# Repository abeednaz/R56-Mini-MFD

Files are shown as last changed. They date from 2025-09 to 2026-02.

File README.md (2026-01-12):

<h1>R56 MINI Cooper Multi-Function Display</h1>

---

<h2>Project Background</h2>
The second generation of BMW MINI Cooper S is a great car, but it is missing important metrology from the factory. It has a coolant temperature sensor, but there is no gauge to view the temperature. Technically a driver can view the temperature by entering a <a href="https://youtu.be/KhFTyjIRaBU?si=EUw38T1VuMLcuM9A">secret menu</a>, but this is not practical except for debugging purposes as it requires a long series of inputs to display. The car otherwise uses the coolant temperature sensor only to flash a warning light when the engine has already overheated. 

Knowledge of engine temperature is important to me for two reasons:

- Situational awareness to know when engine is up to temperature in order to use full throttle and rev range
- Situational awareness in case of cooling system failures, such as leaking plastic thermostat housing

Aftermarket solutions such as the ScanGauge II and CravenSpeed Gauge Kit exist; however I felt that the ScanGauge did not suit the interior design style of the MINI, and the CravenSpeed kit cost cost more than I was willing to spend on an accessory. This project aimed to add an engine temperature display to the MINI that fits the MINI's interior design language and to take advantage of other sensors that the vehicle has to offer.

<h2>Project Demonstrations</h2>

<h3>Scrolling through the different available sensors</h3>

https://github.com/user-attachments/assets/e3969205-8839-4358-a2c1-934d2600cd6b

<h3>Getting engine up to operating temperature</h3>

https://github.com/user-attachments/assets/219b7ffb-3163-47f8-8801-7a190b6d4f65

<h3>Boost pressure demonstration</h3>

https://github.com/user-attachments/assets/48d6ecf0-7964-4478-b5fc-5cb366bfa986

<h2>Project Block Diagram</h2>

R56_MFD_block_diagram

This project consists of the following components:
- COTS ESP32-based microcontroller with AMOLED screen
- COTS ELM327 OBD-II diagnostic code scanner
- Custom PCB to supply ELM327 and ESP32 with 5V and 12V only when vehicle ignition is switched on
- Custom PCB to provide microcontroller with button, ambient light sensor, and 5V from the power supply PCB

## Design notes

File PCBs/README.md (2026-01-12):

# PCB Overview

## OBD-II Connector Board
The connector board connects to the J1962 connector under the vehicle's steering column. Pinout of the vehicle's connector:


The connector board reroutes the battery power (pin 16) through a MOSFET switch triggered by the ignition signal (pin 1). The 12V switched power line is distributed to an ELM327 OBD-II code scanner, a 12V DC power connector, and a 12V--5V buck converter to power the gauge electronics. This allows the code scanner and gauge to only be switched on while the vehicle is in accesory mode or the engine is running, reducing the parasitic battery drain while the vehicle is off to ~145 nW.



### Connector board v2.7 rework:
Two components (SW1 and Q2) were captured incorrectly in the schematic and PCB. The rework instructions are as follows:
1. Remove SW1 and solder wire between P1 and P2
2. Cut trace at X1
3. Cut trace at X2
4. Solder wire between P3 and P4
5. Solder wire between P5 and P6

 PCB Front                 | PCB Back
:-------------------------:|:-------------------------:
conn_board_2-7_rework_front  |  conn_board_2-7_rework_back

### Assembly photos
 Soldered assembly front   | Soldered assembly back    | With connector
:-------------------------:|:-------------------------:|:--------------:|
conn_board_2-7_pic1 |  conn_board_2-7_pic2 | conn_board_2-7_pic3

## Screen Accessory Board
The screen used for this project is an off-the-shelf solution from [Waveshare](https://www.waveshare.com/wiki/ESP32-S3-Touch-AMOLED-1.75#Hardware_Description). It is a fully-contained solution with an ESP32-S3 microprocesor and a high-resolution AMOLED screen in addition to a PMIC and IMU. To adapt it for the gauge, I needed to add a button to allow a user to switch between gauges, and I needed a sensor to check the ambient light level to dim the display at night. I also needed a way to switch the gauge on and off, so I moved the switch from the OBD-II distribution board to the screen accessory board.



 PCB Front                 | PCB Back
:-------------------------:|:-------------------------:
 | 

### Assembly photos
 Soldered assembly front   | Soldered assembly back    
:-------------------------:|:-------------------------:
screen_board_1-0_assembly2 |  screen_board_1-0_assembly1

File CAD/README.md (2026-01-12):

<h1>Mechanical Design</h1>

---

This project required two mechanical assemblies: one to house the OBD-II distribution PCB, and one to attach the gauge screen to the tachometer.

<table>
  <tr>
    <th scope="row" colspan="3"><h2>OBD-II Distribution Board Assembly</h2></th>
  </tr>
  <tr>
    <td>J1962 cable assembly</td>
    <td>Board assembly</td>
    <td>Completed board enclosure</td>
  </tr>
  <tr>
    <td scope="row" colspan="3">This assembly packages the OBD-II distribution PCB along with a J1962 connector to connect the ELM327 wireless code scanner. The J1962 connector is linked to the PCB with a cable assembly with the opposite end being a Molex iGrid 16-pin connector.</td>
  </tr>
</table>

https://github.com/user-attachments/assets/be2643b0-f73f-4a08-8e7a-71b6ab15d59e

<table>
  <tr>
    <th scope="row" colspan="3"><h2>Screen Assembly</h2></th>
  </tr>
  <tr>
    <td>Gauge pod and arm assembly</td>
    <td>Gauge assembled on vehicle</td>
  </tr>
  <tr>
    <td scope="row" colspan="3">This assembly packages the ESP32 AMOLED module with its accessory PCB in a gauge pod which is mounted to the tachometer with an arm. The gauge pod conceals the button underneath the bezel for the user to scroll between different sensors. The screen bezel facing the driver is hinged from the top on two dowel pins, allowing it to flex and press the button similarly to some laptop trackpad buttons. The back bezel contains cutouts for the power switch, ambient light sensor, ESP32 module SD card, and ESP32 module USB-C connector. <br>
      The arm is adapted from a free phone holder from <a href="https://www.printables.com/model/1270372-phone-holder-for-mini-r56r57">Printables</a>. The original tachometer screws are too short when the mount is in place, so two 4mm-wide thread-forming screws were used (I cut mine to ~32mm long).</td>
  </tr>
</table>

https://github.com/user-attachments/assets/c4f2a7ac-ca11-42a1-97a8-a96c77e72be4

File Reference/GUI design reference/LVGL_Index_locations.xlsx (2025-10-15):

 | x |  | y
8 | 55 | -23 | 274
9 | 32 | 23 | 186
10 | 55 | 65 | 98
11 | 120 | 88 | 34
12 | 208 |  | 10
1 | 296 | 88 | 34
2 | 361 | 65 | 98
3 | 384 | 23 | 186
4 | 361 | -23 | 274

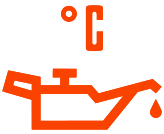
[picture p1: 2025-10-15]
Reference/Gauge images/images/oiltemp_C.png

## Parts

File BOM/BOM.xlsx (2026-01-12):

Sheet: Sheet1
 |  |  |  | TOTAL: | $48.65
Item | Manufacturer | Part number | QTY | Cost | Line total | Subassembly | Notes
Connector board PCB | JLCPCB | Y2-10482731A | 1 | $0.44 | $0.44 | Connector board | Self designed
J1962 Male Connector | Olimex | CONNECTOR-OBD2 | 1 | $2.02 | $2.02 | Connector board
iGrid 16-pin Receptacle | Molex | 5016451620 | 1 | $0.37 | $0.37 | Connector board
Nano-fit 2-pin connector header | Molex | 1053131102 | 2 | $0.70 | $1.41 | Connector board
TO-220 PMOS Transistor | International Rectifier | IRF9540N | 1 | $0.93 | $0.93 | Connector board
TO-220 NMOS Transistor | International Rectifier | IRF540N | 1 | $0.91 | $0.91 | Connector board
DIN0207 Resistor | (Generic) |  | 2 |  | $0.00 | Connector board
Switch | E-Switch | EG1218 | 0 | $0.76 | $0.00 | Connector board | Did not use for connector board
DC-DC Converter | Traco Power | TSR 1-2450E | 1 | $5.08 | $5.08 | Connector board
J1962 Female Connector Housing | TE Connectivity | 179631-2 | 1 | $1.43 | $1.43 | ELM327 to connector board
J1962 Female Connector Terminal contact | TE Connectivity | 776001-1 | 16 | $0.15 | $2.43 | ELM327 to connector board
iGrid 16-pin connector housing | Molex | 5016461600 | 1 | $0.20 | $0.20 | ELM327 to connector board
iGrid 16-pin connector Terminal contact | Molex | 5016471000 | 16 | $0.01 | $0.21 | ELM327 to connector board
Wire | (Generic) |  |  |  | $0.00 | ELM327 to connector board
Wire | (Generic) |  |  |  | $0.00 | Connector board to screen board
Nano-fit 2-pin connector housing | Molex | 1053071202 | 2 | $0.20 | $0.39 | Connector board to screen board
Terminal contact Nano-fit | Molex | 1053002100 | 4 | $0.06 | $0.23 | Connector board to screen board
Screen accessory board PCB | JLCPCB | Y5-10482731A | 1 | $0.44 | $0.44 | Gauge pod | Self designed
ESP32-S3 AMOLED module | Waveshare | ESP32-S3-Touch-AMOLED-1.75 | 1 | $29.99 | $29.99 | Gauge pod
Disc capacitor | (Generic) |  | 1 |  |  | Gauge pod
DO-15 diode | (Generic) | 1N5917 | 1 |  |  | Gauge pod
Male pin header 1x8 | (Generic) |  | 1 |  |  | Gauge pod
DIN0207 Resistor | (Generic) |  | 2 |  | $0.00 | Gauge pod
Light-dependent resistor | (Generic) |  | 1 |  |  | Gauge pod
Pushbutton SPST-NO | C&K | PTS647SN50SMTR2 | 1 | $0.18 |  | Gauge pod
Nano-fit 2-pin connector header | Molex | 1053131102 | 2 | $0.70 | $1.41 | Gauge pod
Switch | E-Switch | EG1218 | 1 | $0.76 | $0.76 | Gauge pod
PETG Filament
Dowel pin

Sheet: Connector board KiCad BOM
Reference | Value | Datasheet | Footprint | Qty | DNP
J1 | Conn_02x08_Top_Bottom | ~ | Connector_Molex:CONN16_5016451620_MOL_Renumbered | 1
J2 | Conn_02x08_J1962_Male | ~ | OBD_connectors:OBD-II_Male_Connector_Renumbered | 1
J3 | Conn_01x02_Socket | ~ | Connector_Molex:CONN02_2125280200_MOL | 2
J4 | Conn_01x02_Socket | ~ | Connector_Molex:CONN02_2125280200_MOL | 2
Q1 | IRF540N | http://www.irf.com/product-info/datasheets/data/irf540n.pdf | Package_TO_SOT_THT:TO-220-3_Vertical | 1
Q2 | IRF9540N | http://www.irf.com/product-info/datasheets/data/irf9540n.pdf | Package_TO_SOT_THT:TO-220-3_Vertical | 1
R1 | 10k | ~ | Resistor_THT:R_Axial_DIN0207_L6.3mm_D2.5mm_P10.16mm_Horizontal | 1
R2 | 1Meg | ~ | Resistor_THT:R_Axial_DIN0207_L6.3mm_D2.5mm_P10.16mm_Horizontal | 1
SW1 | SW_SPDT | EG1218 | Button_Switch_THT:SW_1218_EWI | 1
U1 | TSR_1-2450 | http://www.tracopower.com/products/tsr1.pdf | Converter_DCDC:Converter_DCDC_TRACO_TSR-1_THT | 1

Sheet: Screen board KiCad BOM
Reference | Value | Datasheet | Footprint | Qty | DNP
C1 | 0.1uF | ~ | Capacitor_THT:C_Disc_D4.3mm_W1.9mm_P5.00mm | 1
D1 | 1N5817 | ~ | Diode_THT:D_DO-15_P12.70mm_Horizontal | 1
J1 | Conn_01x08_Pin | ~ | Connector_PinHeader_2.54mm:PinHeader_1x08_P2.54mm_Vertical | 1
J2 | Conn_01x02_Socket | ~ | Connector_Molex:Molex_Nano-Fit_105313-xx02_1x02_P2.50mm_Horizontal | 1
R1 | 10k | ~ | Resistor_THT:R_Axial_DIN0207_L6.3mm_D2.5mm_P10.16mm_Horizontal | 2
R2 | 10k | ~ | Resistor_THT:R_Axial_DIN0207_L6.3mm_D2.5mm_P10.16mm_Horizontal | 2
R3 | LDR | http://www.tme.eu/de/Document/f2e3ad76a925811312d226c31da4cd7e/LDR07.pdf | OptoDevice:R_LDR_5.1x4.3mm_P3.4mm_Vertical_(respaced_silkscreen) | 1
SW1 | 1825910-6 |  | Button_Switch_THT:SW_1825910-6-4 | 1
SW2 | SW_SPDT | ~ | Button_Switch_THT:SW_1218_EWI | 1

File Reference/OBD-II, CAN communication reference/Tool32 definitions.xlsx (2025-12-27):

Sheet: E90
CAN_ID_DEZ | CAN_ID_HEX | CAN_ID_NAME | CAN_ID_NAME(english translation) | DIAG_ID_DEZ | DIAG_ID_HEX | SG_NAME | Source: | https://www.bimmerforums.com/forum/showthread.php?2298830-E90-Can-bus-project-%28E60-E65-E87-%29&p=29628499
0 | 0x00 | unbekannt | Unknown | 0 | 0x00 | Sender unbekannt
949 | 0x3B5 | Status Wasserventil [6] | Water valve status [6] | 120 | 0x78 | IHKA
957 | 0x3BD | Status Verbraucherabschaltung [2] | Consumer shutdown status [2] | 114 | 0x72 | KBM
250 | 0xFA | Steuerung Fensterheber FAT [10] | Power window control FAT [10] | 0 | 0x0 | KGM
251 | 0xFB | Steuerung Fensterheber BFT [5] | Power window control BFT [5] | 0 | 0x0 | KGM
252 | 0xFC | Steuerung Fensterheber FATH [5] | Power window control FATH [5] | 114 | 0x72 | KBM
253 | 0xFD | Steuerung Fensterheber BFTH [5] | Power window control BFTH [5] | 114 | 0x72 | KBM
168 | 0xA8 | Drehmoment 1 K-CAN [10] | Torque 1 K-CAN [10] | 18 | 0x12 | DME1/DDE1
169 | 0xA9 | Drehmoment 2 (10) | Torque 2 (10) | 18 | 0x12 | DME1/DDE1
170 | 0xAA | Drehmoment 3 K-CAN [10] | Torque 3 K-CAN [10] | 18 | 0x12 | DME1/DDE1
172 | 0xAC | Radmoment Antriebsstrang 2 [5] | Wheel torque drivetrain 2 [5] | 18 | 0x12 | DME1/DDE1
173 | 0xAD | Verzögerungsanforderung ACC [9] | ACC deceleration request [9] | 28 | 0x1C | LDM
173 | 0xAD | Verzögerungsanforderung ACC [9] | ACC deceleration request [9] | 33 | 0x21 | ACC_Modul/ACC+NAVI
179 | 0xB3 | Steuerung Lenkunterstützung [2] | Power steering control [2] | 22 | 0x16 | AFS
180 | 0xB4 | Radmoment Antriebsstrang 1 [4] | Wheel torque drivetrain 1 [4] | 18 | 0x12 | DME1/DDE1
181 | 0xB5 | Drehmomentanforderung EGS [9] | Torque request EGS [9] | 24 | 0x18 | EGS_MECH+NAVI/EGS_MECH
182 | 0xB6 | Drehmomentanforderung DSC [7] | Torque request DSC [7] | 41 | 0x29 | DXC_RB/DSC_RB/DSC_CT
183 | 0xB7 | Drehmomentanforderung ACC [10] | Torque request ACC [10] | 28 | 0x1C | LDM
183 | 0xB7 | Drehmomentanforderung ACC [10] | Torque request ACC [10] | 33 | 0x21 | ACC_Modul/ACC+NAVI
184 | 0xB8 | Drehmomentanforderung DKG [2] | Torque request DKG [2] | 24 | 0x18 | DKG
185 | 0xB9 | Drehmomentanforderung AFS [3] | Torque request AFS [3] | 22 | 0x16 | AFS
186 | 0xBA | Getriebedaten [20] | Transmission data [20] | 24 | 0x18 | SMG_M/SMG/EGS_MECH+NAVI/EGS_MECH/DKG
187 | 0xBB | Sollmomentanforderung [7] | Target torque request [7] | 41 | 0x29 | DXC_RB
188 | 0xBC | Status Sollmomentumsetzung [7] | Target torque implementation status [7] | 25 | 0x19 | VGSG
189 | 0xBD | Drehmomentanforderung SSG [6] | Torque request SSG [6] | 24 | 0x18 | SMG_M/SMG
190 | 0xBE | Alive Zähler [12] | Alive counter [12] | 35 | 0x23 | ARS_Modul
191 | 0xBF | Anforderung Radmoment Antriebsstrang [6] | Wheel torque drivetrain request [6] | 28 | 0x1C | LDM
192 | 0xC0 | Alive Zentrales Gateway [1] | Alive central Gateway [1] | 0 | 0x0 | KGM
193 | 0xC1 | Alive Zähler Telefon [3] | Alive Counter Telephone [3] | 54 | 0x36 | TEL_JAP/TEL_BPI
196 | 0xC4 | Lenkradwinkel K-CAN [13] | Steering Wheel Angle K-CAN [13] | 41 | 0x29 | DXC_RB/DSC_RB/DSC_CT
200 | 0xC8 | Lenkradwinkel Oben K-CAN [6] | Steering Wheel Angle Up K-CAN [6] | 2 | 0x2 | SZL_LWS
206 | 0xCE | Radgeschwindigkeit K-CAN [4] | Wheel Speed K-CAN [4] | 41 | 0x29 | DXC_RB/DSC_RB/DSC_CT
210 | 0xD2 | Bedienung Sitzverstellung BF [6] | Seat Adjustment Control BF [6] | 101 | 0x65 | SZM_MIT_KBUS/SZM
213 | 0xD5 | Anforderung Radmoment Bremse [6] | Wheel Torque Brake Request [6] | 28 | 0x1C | LDM
215 | 0xD7 | Alive Zähler Sicherheit [2] | Alive Counter Safety [2] | 1 | 0x1 | ACSM
218 | 0xDA | Bedienung Sitzverstellung FA [6] | Seat Adjustment Control FA [6] | 101 | 0x65 | SZM_MIT_KBUS/SZM
225 | 0xE1 | Radmoment Bremse [3] | Wheel Torque Brake [3] | 41 | 0x29 | DXC_RB/DSC_RB
226 | 0xE2 | Status Zentralverriegelung BFT [11] | Central Locking Status BFT [11] | 0 | 0x0 | KGM
230 | 0xE6 | Status Zentralverriegelung BFTH [11] | Central Locking Status BFTH [11] | 114 | 0x72 | KBM
234 | 0xEA | Status Zentralverriegelung FAT [11] | Central Locking Status FAT [11] | 0 | 0x0 | KGM

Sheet: R56
ARG | ID | RESULTNAME | DATENTYP | L/H | EINHEIT | NAME | MUL | DIV | ADD | LABEL | INFO | English translation | Source: Tool32 on D60PSA0.prg, open Tabellen-info->MESSWERTETAB
ISKLV | 0x1392 | STAT_KLIMA_VERBAUT_WERT | unsigned int | - | [-] | - | 1 | - | 0 | ACCD_stACPresent | Klimaanlage im Auto vorhanden | Air conditioning in the car
ACCtl_trqLim | 0x139C | STAT_ACCtl_trqLim_WERT | unsigned int | - | [Nm] | - | 0.114445 | - | -2500.060084 | ACCtl_trqLim | Contains Limited Torque | Contains Limited Torque
INLKG | 0x13A6 | STAT_LUFTMASSE_NORMALISIERT_WERT | unsigned int | - | [Kg/h] | - | 0.048829 | - | -1599.971484 | AFSCD_dmAirNorm | Normalisierte Luftmasse | Normalized air mass
ILMKG | 0x0080 | STAT_LUFTMASSE_WERT | unsigned int | - | [Kg/h] | - | 0.048829 | - | -1599.971484 | AFSCD_dmAirPerTime | HFM Luftmassenstrom | HFM air mass flow
RLMKG | 0x0010 | STAT_LUFTMASSE_ROH_WERT | unsigned int | - | [Kg/h] | - | 0.036001 | - | 0 | AFSCD_dmAirRawPerTime | LMM Luftmassenmesser HFM | HFM air mass meter
ILMMG | 0x0081 | STAT_LUFTMASSE_PRO_HUB_WERT | unsigned int | - | [mg/Hub] | - | 0.048829 | - | -1599.971484 | AFSCD_mAirPerCyl | angesaugte Luftmasse pro Zylinder | Intake air mass per cylinder
ITTAN | 0x0083 | STAT_ANSAUGLUFTTEMPERATUR_TASTVERHAELTNIS_WERT | unsigned int | - | [%] | - | 0.01 | - | 0 | AFSCD_rAir | duty cycle of the air temparature signal | Duty cycle of the air temperature signal
ITANSHFM | 0x000F | STAT_ANSAUGLUFTTEMPERATUR_HFM_WERT | unsigned int | - | [deg C] | - | 1.00024 | - | -41.084307 | AFSCD_tAir_mp | linearisierter Wert aus HWK vorm Aufruf der Übergangsfunktion | Linearized value from HWK before calling the transfer function
RLMPE | 0x13A7 | STAT_LUFTMASSE_PERIODENDAUER_ROH_WERT | unsigned int | - | us | - | 0.035714 | - | 0 | AFSCD_tiRaw | Periodendauerrohwert des Luftmassensensors | Raw period duration value of the air mass sensor
ITZUH | 0x0085 | STAT_ZUHEIZER_ANSTEUERUNG_WERT | unsigned int | - | [%] | - | 0.01 | - | 0 | AOHtCD_rOut_mp | Meßpunkt fuer korrigiertes Tastverhaeltnis der Zuheizeransteuerung | Measurement point for corrected duty cycle of the auxiliary heater control
AOHt_stShutOff_mp | 0x13B0 | STAT_AOHt_stShutOff_mp | unsigned int | - | [-] | - | 1 | - | 0 | AOHt_stShutOff_mp | Überblick auf alle Abschaltbedingungen | Overview of all shutdown conditions
IFPWG | 0x0086 | STAT_FAHRERWUNSCH_PEDAL_WERT | unsigned int | - | [%] | - | 0.003052 | - | 0 | APPCD_rFlt | gefiltertes Pedalwertgebersignal | Filtered pedal value signal
IKICK | 0x13BA | STAT_KICKDOWNSCHALTER_WERT | unsigned int | - | [-] | - | 1 | - | 0 | APPCD_stKickDown | Schalter KIck Down | Kick-down switch
IUPW1 | 0x0089 | STAT_PWG1_SPANNUNG_WERT | unsigned int | - | V | - | 0.000611 | - | 0 | APPCD_uRawAPP1 | Fahrpedal 1 Position Rohwert | Accelerator pedal 1 position raw value
IUPW2 | 0x008A | STAT_PWG2_SPANNUNG_WERT | unsigned int | - | V | - | 0.000611 | - | 0 | APPCD_uRawAPP2 | Fahrpedal 2 Position Rohwert | Accelerator pedal 2 position raw value
IPUMG | 0x008B | STAT_UMGEBUNGSDRUCK_WERT | unsigned int | - | [hPa] | - | 0.125002 | - | 0 | APSCD_pVal | Atmosphärendruck | Atmospheric pressure
IUUMG | 0x008C | STAT_UMGEBUNGSDRUCK_SPANNUNG_WERT | unsigned int | - | [mV] | - | 0.610958 | - | 0 | APSCD_uRaw | Rohspannung ADC-Signal Atmosphärendruck | Raw voltage ADC signal atmospheric pressure
IMARD | 0x13C4 | STAT_MOMENTFORDERUNG_ARD_WERT | unsigned int | - | [Nm] | - | 0.114445 | - | -2500.060084 | ASDdc_trq | Momentforderung Aktiver Ruckeldämpfer (Störungsregler) | Torque demand Active Jerk Damper (disturbance controller)
IFWUR | 0x13CE | STAT_FAHRERWUNSCHMOMENT_ROH_WERT | unsigned int | - | [Nm] | - | 0.114445 | - | -2500.058653 | AccPed_trqDes | Fahrerwunsch Rohwert | Driver request raw value
SLMMG | 0x008D | STAT_LUFTMASSE_SOLL_WERT | unsigned int | - | [mg/Hub] | - | 0.048829 | - | -1599.971484 | AirCtl_mDesVal | Luftmassensollwert | Air mass setpoint
ILMRE | 0x13E2 | STAT_LUFTMASSE_REGELABWEICHUNG_WERT | unsigned int | - | [mg/Hub] | - | 0.048829 | - | -1599.971484 | AirCtl_mGvnrDvt | Regelabweichung | Control deviation
IGENL | 0x008E | STAT_GENERATORLAST_WERT | unsigned int | - | [%] | - | 0.003052 | - | 0 | AltCD_rAltLoad | linearisiertes und fehlerentprelltes Generatorlastsignals | Linearized and debounced generator load signal
IALDS | 0x008F | STAT_LADEDRUCKSTELLER_ANSTEUERUNG_WERT | unsigned int | - | [%] | - | 0.01 | - | 0 | BPACD_rOut | Tastverhältnis zür Endstufenansteuerung | Duty cycle for power stage control
BPSCD_pLin | 0x000B | STAT_BPSCD_pLin_WERT | unsigned int | - | [hPa] | - | 10.002401 | - | 0 | BPSCD_pLin | Mittelere Ladedruck-Wert (liniarisiert) | Average boost pressure value (linearized)
IPLAD | 0x0091 | STAT_LADEDRUCK_WERT | unsigned int | - | [hPa] | - | 0.125002 | - | 0 | BPSCD_pOutVal | Ladedruckwert | Boost pressure value
IULDF | 0x0092 | STAT_LADEDRUCK_SPANNUNG_WERT | unsigned int | - | [mV] | - | 0.610958 | - | 0 | BPSCD_uRawVal | Spannungsrohwert des Ladedrucksensors | Raw voltage value of the boost pressure sensor
IUBAT | 0x0093 | STAT_UBATT_WERT | unsigned int | - | V | - | 0.002456 | - | 0 | BattCD_u | Batteriespannung | Battery voltage
BrkCD_ctUnPlaus_mp | 0x13EE | STAT_BrkCD_ctUnPlaus_mp_WERT | unsigned int | - | [-] | - | 1 | - | 0 | BrkCD_ctUnPlaus_mp | Debounce counter of break-plausibility-check | Debounce counter of brake plausibility check
ISBLS | 0x13EC | STAT_BREMSLICHTSCHALTER_EIN_WERT | unsigned int | - | [-] | - | 1 | - | 0 | BrkCD_stMnSwtRawVal | Rohwert Bremskontakt nicht entprellt | Raw value brake contact not debounced
ISBLT | 0x13ED | STAT_BREMSLICHTTESTSCHALTER_EIN_WERT | unsigned int | - | [-] | - | 1 | - | 0 | BrkCD_stRedSwtRawVal | Rohwert redundanter Bremskontakt nicht entprellt | Raw value redundant brake contact not debounced
ITKUM | 0x0095 | STAT_KUEHLMITTELTEMPERATUR_WERT | unsigned int | - | [deg C] | - | 0.016787 | - | -50.13844 | CTSCD_tClnt | Kühlmitteltemperatur | Coolant temperature
CTSCD_tClntLin | 0x0005 | STAT_CTSCD_tClntLin_WERT | unsigned int | - | [deg C] | - | 1.00024 | - | -41.084307 | CTSCD_tClntLin | linearisierter Wert aus HWK vorm Aufruf der Übergangsfunktion | Linearized value from HWK before calling the transfer function
RUTKU | 0x0096 | STAT_KUEHLMITTELTEMPERATUR_SPANNUNG_ROH_WERT | unsigned int | - | [mV] | - | 0.610958 | - | 0 | CTSCD_uRaw | Wassertemperatur Spannungsrohwert | Water temperature raw voltage value
ICLGDT | 0x13FD | STAT_KUEHLER_TEMPERATURANSTIEG_SEIT_START_WERT | unsigned int | - | [K] | - | 0.0125 | - | -50.000763 | Clg_dtDynTst | rise in temperature since start of test | Rise in temperature since start of test
IDLGTEND | 0x13FF | STAT_KUEHLER_TEMPERATUR_BEI_TESTENDE_WERT | unsigned int | - | [deg C] | - | 0.016787 | - | -50.13844 | Clg_tEndDynTst | CTSCD_tClnt at the end of test | CTSCD_tClnt at the end of test
ICLGTI | 0x13FC | STAT_KUEHLER_TESTDAUER_WERT | unsigned int | - | [s] | - | 0.999001 | - | 0 | Clg_tiDynTst | actual time of test | Actual time of test
IAMMM | 0x0004 | STAT_VERHAELTNIS_AKTUELLES_MOMENT_MAXIMALMOMENT_WERT | unsigned int | - | [%] | - | 0.393699 | - | 0 | CoEng_rTrq | Verhältnis aktuelles Moment zu Maximalmoment | Ratio of current torque to maximum torque
INAZU | 0x1B6C | STAT_NACHLAUFZUSTAND | unsigned int | - | [-] | - | 1 | - | 0 | CoEng_stAftRun | State variable of the afterrun state machine | State variable of the afterrun state machine
ISABU | 0x1450 | STAT_TYP_WIRKSAME_ABSCHALTURSACHE_WERT | unsigned int | - | [-] | - | 1 | - | 0 | CoEng_stShutOff | Typ der wirksamen Abschaltursache (0: Nachlauf; 1: reversibel; 2: irreversibel) | Type of effective shutdown cause (0: afterrun; 1: reversible; 2: irreversible)
IMOAK | 0x0097 | STAT_MOTORMOMENT_AKTUELL_WERT | unsigned int | - | [Nm] | - | 0.114445 | - | -2500.060084 | CoEng_trq | current engine torque output | Current engine torque output
SMIBA | 0x1451 | STAT_MOTORMOMENT_SOLL_NACH_BEGRENZUNG_VOR_ARD_WERT | unsigned int | - | [Nm] | - | 0.114445 | - | -2500.060084 | CoEng_trqInrLtd | inneres Moment Sollwert nach Begrenzung, vor Eingriff ARD-Störungsregler | Internal torque setpoint after limitation, before ARD disturbance controller intervention
SMOMO | 0x00EE | STAT_MOTORMOMENT_SOLL_WERT | unsigned int | - | [Nm] | - | 0.114445 | - | -2500.060084 | CoEng_trqInrSet | inneres Moment Sollwert (>Mengenberechnung) | Internal torque setpoint (>quantity calculation)
IMBEG | 0x1453 | STAT_MOTORMOMENT_BEGRENZUNG_WERT | unsigned int | - | [Nm] | - | 0.114445 | - | -2500.060084 | CoEng_trqLimMin_mp | Begrenzungsmoment, falls kein momentenbegrenzender Systemfehler vorliegt (Minimum aus Rauchgrenze un Motormech.schutz) | Limiting torque if no torque-limiting system fault is present (minimum of smoke limit and engine mechanical protection)
IMWVO | 0x1464 | STAT_MOTORMOMENT_WUNSCH_WERT | unsigned int | - | [Nm] | - | 0.114445 | - | -2500.058653 | CoVM_trqPrpDes | Wunsch Vortriebsmoment | Desired propulsion torque
RSKUP | 0x146E | STAT_KUPPLUNGSSCHALTER_ROH_WERT | unsigned int | - | [-] | - | 1 | - | 0 | ConvCD_stRawVal | Kupplungssignal Rohwert | Clutch signal raw value
CrCCD_stKey | 0x1482 | STAT_CrCCD_stKey_WERT | unsigned int | - | [-] | - | 1 | - | 0 | CrCCD_stKey | Rückgabewert | Return value
IGAFG | 0x148C | STAT_GANG_FGR_WERT | unsigned int | - | [-] | - | 1 | - | 0 | CrCtl_numGear | Gang FGR | Gear FGR
ISFGL | 0x148D | STAT_LAMPE_FGR_EIN_WERT | unsigned int | - | [-] | - | 1 | - | 0 | CrCtl_stLampOut | Status der CrCtl-Lampe (wird über CAN versendet) | Status of the CrCtl lamp (transmitted via CAN)
CrCtl_stShutOffCode1_mp | 0x148E | STAT_CrCtl_stShutOffCode1_mp_WERT | unsigned int | - | [-] | - | 1 | - | 0 | CrCtl_stShutOffCode1_mp | Low Byte von CrCtl_shutOffCode (Verwendung als Signal) | Low byte of CrCtl_shutOffCode (used as a signal)
CrCtl_stShutOffCode2_mp | 0x148F | STAT_CrCtl_stShutOffCode2_mp_WERT | unsigned int | - | [-] | - | 1 | - | 0 | CrCtl_stShutOffCode2_mp | Low Byte von CrCtl_shutOffCode (Verwendung als Signal) | Low byte of CrCtl_shutOffCode (used as a signal)
CrCtl_stShutOffFrz1_mp | 0x1490 | STAT_CrCtl_stShutOffFrz1_mp_WERT | unsigned int | - | [-] | - | 1 | - | 0 | CrCtl_stShutOffFrz1_mp | latched shutoff reason | Latched shutoff reason
CrCtl_stShutOffFrz2_mp | 0x1491 | STAT_CrCtl_stShutOffFrz2_mp_WERT | unsigned int | - | [-] | - | 1 | - | 0 | CrCtl_stShutOffFrz2_mp | latched shutoff reason | Latched shutoff reason
IMANF | 0x1492 | STAT_MOTORMOMENT_ANFORDERUNG_FGR_WERT | unsigned int | - | [Nm] | - | 0.114445 | - | -2500.058653 | CrCtl_trqDes | Momentenanforderung FGR | Current FGR request
SGEFG | 0x1493 | STAT_GESCHWINDIGKEIT_FGR_SOLL_WERT | unsigned int | - | [km/h] | - | 0.003815 | - | 0 | CrCtl_vDes | Sollgeschwindigkeit FGR | Target speed FGR
DSMDur_ctDfctDur1 | 0x14B4 | STAT_DSMDur_ctDfctDur1_WERT | unsigned int | - | [-] | - | 1 | - | 0 | DSMDur_ctDfctDur1 | Wert Fehlerdauerzähler | Value of fault duration counter
IMILANKM | 0x0021 | STAT_WEGSTRECKE_MIT_MIL_AN_WERT | unsigned int | - | [-] | - | 1 | - | 0 | DSMDur_ctDfctDur1_Carb | OBD: Travelled Distance with MIL on | OBD: Travelled Distance with MIL on
DSMDur_ctDfctDur2 | 0x14B5 | STAT_DSMDur_ctDfctDur2_WERT | unsigned int | - | [-] | - | 1 | - | 0 | DSMDur_ctDfctDur2 | Wert Fehlerdauerzähler 2 | Value of fault duration counter 2
DSMDur_stGlobalDefCnt_mp | 0x14B6 | STAT_DSMDur_stGlobalDefCnt_mp_WERT | unsigned int | - | [-] | - | 1 | - | 0 | DSMDur_stGlobalDefCnt_mp | Aktivierungs und Resetzustand der beiden globalen Fehlerdauerzähler | Activation and reset status of the two global fault duration counters
IAOBF | 0x14B7 | STAT_ANZAHL_OBD_FEHLER_IM_FEHLERSPEICHER_WERT | unsigned int | - | [-] | - | 1 | - | 0 | DSM_ctOBDPath | Anzahl der momentanen OBD-fehler im Fehlerspeicher | Number of current OBD faults in the fault memory
DSM_ctRdyActCyc_mp | 0x14B8 | STAT_DSM_ctRdyActCyc_mp_WERT | unsigned int | - | [-] | - | 1 | - | 0 | DSM_ctRdyActCyc_mp | Status für jedes Readinessbit aus dem aktuellen driving cycle | Status for each readiness bit from the current driving cycle
DSM_ctRdyTstCompr_mp | 0x14B9 | STAT_DSM_ctRdyTstCompr_mp_WERT | unsigned int | - | [-] | - | 1 | - | 0 | DSM_ctRdyTstCompr_mp | Anzahl von in diesem Zyklus getesteten Fehlerpfaden die zum Readiness Bit Comprehensive Components gehören. | Number of fault paths tested in this cycle that belong to the Comprehensive Components readiness bit.
DSM_ctRdyTstEGR_mp | 0x14BA | STAT_DSM_ctRdyTstEGR_mp_WERT | unsigned int | - | [-] | - | 1 | - | 0 | DSM_ctRdyTstEGR_mp | Anzahl von in diesem Zyklus getesteten Fehlerpfaden die zum Readiness Bit EGR gehören. | Number of fault paths tested in this cycle that belong to the EGR readiness bit.
DSM_ctRdyTstFuel_mp | 0x14BB | STAT_DSM_ctRdyTstFuel_mp_WERT | unsigned int | - | [-] | - | 1 | - | 0 | DSM_ctRdyTstFuel_mp | Anzahl von in diesem Zyklus getesteten Fehlerpfaden die zum Readiness Bit Fuel System gehören. | Number of fault paths tested in this cycle that belong to the Fuel System readiness bit.
DSM_ctRdyTstMisf_mp | 0x14BC | STAT_DSM_ctRdyTstMisf_mp_WERT | unsigned int | - | [-] | - | 1 | - | 0 | DSM_ctRdyTstMisf_mp | Anzahl von in diesem Zyklus getesteten Fehlerpfaden die zum Readiness Bit Misfire gehören. | Number of fault paths tested in this cycle that belong to the Misfire readiness bit. Number of tested fault paths
IFEHAN | 0x14BD | STAT_ANZAHL_GETESTETE_FEHLERPFADE_WERT | unsigned int | - | [-] | - | 1 | - | 0 | DSM_ctTstPath | Anzahl der getesteten Fehlerpfade | Number of tested fault paths
DSM_stCycles | 0x14BE | STAT_DSM_stCycles_WERT | unsigned int | - | [-] | - | 1 | - | 0 | DSM_stCycles | Status der DSM Trigger Zyklen (WUC, DC, ...) | Status of DSM trigger cycles (WUC, DC, ...)
ISMIL | 0x14BF | STAT_MIL_EIN_WERT | unsigned int | - | [-] | - | 1 | - | 0 | DSM_stMIL | DSM Mil Anforderungsstatus (1 = kontinuierlich, 2 blinkend) | DSM MIL request status (1 = continuous, 2 flashing)
ISRAB | 0x14C0 | STAT_READINESS_BYTES_AB_WERT | unsigned int | - | [-] | - | 1 | - | 0 | DSM_stRdyAB | Readiness Status für Diagnoseschnittstelle gemäß SAE J1979 PID1 Byte A + B | Readiness status for diagnostic interface according to SAE J1979 PID1 Byte A + B
ISRCD | 0x14C1 | STAT_READINESS_BYTES_CD_WERT | unsigned int | - | [-] | - | 1 | - | 0 | DSM_stRdyCD | Readiness Status für Diagnoseschnittstelle gemäß SAE J1979 PID1 Byte C * D | Readiness status for diagnostic interface according to SAE J1979 PID1 Byte C * D
ISSLA | 0x14C2 | STAT_ANFORDERUNGSSTATUS_SYSTEMLAMPE_WERT | unsigned int | - | [-] | - | 1 | - | 0 | DSM_stSysLamp | DSM System Lampen Anforderungsstatus (1 = kontinuierlich) | DSM system lamp request status (1 = continuous)
DSM_tiDCDelay_mp | 0x14C3 | STAT_DSM_tiDCDelay_mp_WERT | unsigned int | - | [-] | - | 1 | - | 0 | DSM_tiDCDelay_mp | aktuelle Zeit für Driving cycle Verzögerungszeit | Current time for driving cycle delay time
IAAGR | 0x0099 | STAT_ABGASRUECKFUEHRSTELLER_ANSTEUERUNG_WERT | unsigned int | - | [%] | - | 0.01 | - | 0 | EGRCD_rOut | Tastverhältnis zür Endstufenansteuerung | Duty cycle for power stage control
EGT_st | 0x009B | STAT_EGT_st_WERT | unsigned int | - | [-] | - | 1 | - | 0 | EGT_st | Regenerationsanforderung fuer Abgasnachbehandlung (drehzahlsynchron) | Regeneration request for exhaust gas aftertreatment (engine speed synchronous)
ISSYN | 0x009D | STAT_SYNCHRONISATION_KW_NW_WERT | unsigned int | - | [-] | - | 1 | - | 0 | EngM_stSync | Meta-Status der KW- und NW-Ereignisverwaltung (Motorpositions-Management) | Meta-status of crankshaft and camshaft event management (engine position management)
IMORE | 0x1554 | STAT_REIBMOMENT_AKTUELL_WERT | unsigned int | - | [Nm] | - | 0.114445 | - | -2500.060084 | EngM_trqFrc | aktuelles Reibmoment | Current friction torque
INMOT | 0x009E | STAT_MOTORDREHZAHL_WERT | unsigned int | - | [rpm] | - | 0.125002 | - | 0 | Eng_nAvrg | mittlere Motordrehzahl | Average engine speed
INMOTCARB | 0x000C | STAT_MOTORDREHZAHL_WERT | unsigned int | - | [rpm] | - | 0.25 | - | 0 | Eng_nAvrg_Carb | mittlere Motordrehzahl | Average engine speed
ErLpCD_stMil | 0x155E | STAT_ErLpCD_stMil_WERT | unsigned int | - | [-] | - | 1 | - | 0 | ErLpCD_stMil | Status of the MIL and source of activation | Status of the MIL and source of activation
IZTF00 | 0x157C | STAT_ZAHNTEILUNGSFEHLER_REL_00_WERT | unsigned int | - | [%] | - | 3.6e-05 | - | -1.170332 | FBC_DXSl_mp[0] | relativer gefilterter Zahnteilungsfehler 00 | Relative filtered tooth pitch error 00
IZTF10 | 0x1586 | STAT_ZAHNTEILUNGSFEHLER_REL_10_WERT | unsigned int | - | [%] | - | 3.6e-05 | - | -1.170332 | FBC_DXSl_mp[10] | relativer gefilterter Zahnteilungsfehler 10 | Relative filtered tooth pitch error 10
IZTF11 | 0x1587 | STAT_ZAHNTEILUNGSFEHLER_REL_11_WERT | unsigned int | - | [%] | - | 3.6e-05 | - | -1.170332 | FBC_DXSl_mp[11] | relativer gefilterter Zahnteilungsfehler 11 | Relative filtered tooth pitch error 11
IZTF01 | 0x157D | STAT_ZAHNTEILUNGSFEHLER_REL_01_WERT | unsigned int | - | [%] | - | 3.6e-05 | - | -1.170332 | FBC_DXSl_mp[1] | relativer gefilterter Zahnteilungsfehler 01 | Relative filtered tooth pitch error 01
IZTF02 | 0x157E | STAT_ZAHNTEILUNGSFEHLER_REL_02_WERT | unsigned int | - | [%] | - | 3.6e-05 | - | -1.170332 | FBC_DXSl_mp[2] | relativer gefilterter Zahnteilungsfehler 02 | Relative filtered tooth pitch error 02
IZTF03 | 0x157F | STAT_ZAHNTEILUNGSFEHLER_REL_03_WERT | unsigned int | - | [%] | - | 3.6e-05 | - | -1.170332 | FBC_DXSl_mp[3] | relativer gefilterter Zahnteilungsfehler 03 | Relative filtered tooth pitch error 03
IZTF04 | 0x1580 | STAT_ZAHNTEILUNGSFEHLER_REL_04_WERT | unsigned int | - | [%] | - | 3.6e-05 | - | -1.170332 | FBC_DXSl_mp[4] | relativer gefilterter Zahnteilungsfehler 04 | Relative filtered tooth pitch error 04
IZTF05 | 0x1581 | STAT_ZAHNTEILUNGSFEHLER_REL_05_WERT | unsigned int | - | [%] | - | 3.6e-05 | - | -1.170332 | FBC_DXSl_mp[5] | relativer gefilterter Zahnteilungsfehler 05 | Relative filtered tooth pitch error 05
IZTF06 | 0x1582 | STAT_ZAHNTEILUNGSFEHLER_REL_06_WERT | unsigned int | - | [%] | - | 3.6e-05 | - | -1.170332 | FBC_DXSl_mp[6] | relativer gefilterter Zahnteilungsfehler 06 | Relative filtered tooth pitch error 06
IZTF07 | 0x1583 | STAT_ZAHNTEILUNGSFEHLER_REL_07_WERT | unsigned int | - | [%] | - | 3.6e-05 | - | -1.170332 | FBC_DXSl_mp[7] | relativer gefilterter Zahnteilungsfehler 07 | Relative filtered tooth pitch error 07
IZTF08 | 0x1584 | STAT_ZAHNTEILUNGSFEHLER_REL_08_WERT | unsigned int | - | [%] | - | 3.6e-05 | - | -1.170332 | FBC_DXSl_mp[8] | relativer gefilterter Zahnteilungsfehler 08 | Relative filtered tooth pitch error 08
IZTF09 | 0x1585 | STAT_ZAHNTEILUNGSFEHLER_REL_09_WERT | unsigned int | - | [%] | - | 3.6e-05 | - | -1.170332 | FBC_DXSl_mp[9] | relativer gefilterter Zahnteilungsfehler 09 | Relative filtered tooth pitch error 09
IMOAI | 0x009F | STAT_MOTORMOMENT_INNERES_AKTUELL_WERT | unsigned int | - | [Nm] | - | 0.114445 | - | -2500.060084 | FMTC_trqInr | aktuelles rückgerechnetes inneres Motormoment | Current calculated internal engine torque
ITKRS | 0x00A0 | STAT_KRAFTSTOFFTEMPERATURK_WERT | unsigned int | - | [deg C] | - | 0.016787 | - | -50.13844 | FTSCD_tFuel | Kraftstofftemperatur | Fuel temperature
ISKRS | 0x00A1 | STAT_KRAFTSTOFFTEMPERATURK_SPANNUNG_ROH_WERT | unsigned int | - | [mV] | - | 0.610958 | - | 0 | FTSCD_uRaw | Spannungsrohwert der Kraftstoffstemperatur | Raw voltage value of the fuel temperature
FlMng_qLimSmk | 0x1568 | STAT_FlMng_qLimSmk_WERT | unsigned int | - | [mg/hub] | - | 0.003052 | - | -99.998993 | FlMng_qLimSmk | FlMng_qLimSmk | FlMng_qLimSmk
ISKME | 0x15E0 | STAT_KILOMETERSTAND_WERT | unsigned int | - | [km] | - | 8 | - | 0 | FrmMng_lSum | Kilometerstand des Fahrzeugs | Vehicle mileage
INELU | 0x15E1 | STAT_ELEKTROLUEFTERDREHZAHL_WERT | unsigned int | - | [1/min] | - | 0.091556 | - | 0 | FrmMng_nFan | Lüfterdrehzahl | Fan speed
FrmMng_nPSP | 0x00A4 | STAT_FrmMng_nPSP_WERT | unsigned int | - | [rpm] | - | 1 | - | 0 | FrmMng_nPSP | Ist-Drehzahl EKP | Actual EKP speed
FrmMng_rPSPSetPoint | 0x00A5 | STAT_FrmMng_rPSPSetPoint_WERT | unsigned int | - | [%] | - | 0.003052 | - | 0 | FrmMng_rPSPSetPoint | EKP-SetPoint | EKP setpoint
IAHEI | 0x15E2 | STAT_HEIZLEISTUNGSANFORDERUNG_UEBER_CAN_WERT | unsigned int | - | [-] | - | 1 | - | 0 | FrmMng_stACHtgReq | Heizleistungsanforderung über CAN | Heating power request via CAN
FrmMng_stPSP | 0x15E3 | STAT_FrmMng_stPSP_WERT | unsigned int | - | [-] | - | 1 | - | 0 | FrmMng_stPSP | EKP - diagnose status | EKP - diagnostic status
ISKLI | 0x15E4 | STAT_KLIMA_EIN_WERT | unsigned int | - | [-] | - | 1 | - | 0 | FrmMng_swtAC_mp | Schalter Klimakompressor | Air conditioning compressor switch
ITUMG | 0x15E5 | STAT_UMGEBUNGSTEMPERATUR_WERT | unsigned int | - | [deg C] | - | 0.016787 | - | -50.13844 | FrmMng_tEnv | Umgebungstemperatur | Ambient temperature
FrmMng_trqAC | 0x15E6 | STAT_FrmMng_trqAC_WERT | unsigned int | - | [Nm] | - | 0.114445 | - | -2500.060084 | FrmMng_trqAC | desired Torque AC | Desired torque AC
IGABE | 0x1644 | STAT_BERECHNETER_GANG_WERT | unsigned int | - | [-] | - | 1 | - | 0 | Gearbx_stGear | Ganginformation | Gear information
IGETT | 0x1645 | STAT_GETRIEBETYP_WERT | unsigned int | - | [-] | - | 1 | - | 0 | Gearbx_swtType | Getriebetyp (0: manuell(MT); 1: automatisch(AT); 2: Schaltautomatisch(AST); 3: StufenlosesGetriebe (CVT); 4:automatic Z-Car) | Transmission type (0: manual (MT); 1: automatic (AT); 2: Automatic transmission (AST); 3: Continuously variable transmission (CVT); 4: Automatic Z-Car)
IAGLL | 0x00A7 | STAT_GLUEHANZEIGE_ANSTEUERUNG_WERT | unsigned int | - | [-] | - | 1 | - | 0 | GlwCtl_stLampOut | Zustand der Glühanzeige | Glow plug indicator status
IBSCD_ibatt_w_mp | 0x00B4 | STAT_IBSCD_ibatt_w_mp_WERT | unsigned int | - | [-] | - | 1 | - | 0 | IBSCD_ibatt_w_mp | Battery current value | Battery current value
HWEMon_numRecovery | 0x00A8 | STAT_HWEMon_numRecovery_WERT | unsigned int | - | [-] | - | 1 | - | 0 | HWEMon_numRecovery | Herkunft des letzten Reset ( >0 = Recovery ) - low byte | Origin of the last reset (>0 = Recovery) - low byte
HWEMon_numRecovery1 | 0x00A9 | STAT_HWEMon_numRecovery1_WERT | unsigned int | - | [-] | - | 1 | - | 0 | HWEMon_numRecovery1 | Herkunft des letzten Reset ( >0 = Recovery ) - high byte | Origin of the last reset (>0 = Recovery) - high byte
HWEMon_recLocHigh_mp | 0x00AC | STAT_HWEMon_recLocHigh_mp_WERT | unsigned int | - | [-] | - | 1 | - | 0 | HWEMon_recLocHigh_mp | Recovery location address - high word - low byte | Recovery location address - high word - low byte
HWEMon_recLocLow_mp | 0x00AA | STAT_HWEMon_recLocLow_mp_WERT | unsigned int | - | [-] | - | 1 | - | 0 | HWEMon_recLocLow_mp | Recovery location address - low word - low byte | Recovery location address - low word - low byte
HWEMon_recLocLow_mp1 | 0x00AB | STAT_HWEMon_recLocLow_mp1_WERT | unsigned int | - | [-] | - | 1 | - | 0 | HWEMon_recLocLow_mp1 | Recovery location address - low word - high byte | Recovery location address - low word - high byte
ITANS | 0x00AD | STAT_ANSAUGLUFTTEMPERATUR_WERT | unsigned int | - | [deg C] | - | 0.016787 | - | -50.13844 | IATSCD_tAir | Ansauglufttemperatur | Intake air temperature
SPEKA | 0x16B2 | STAT_EINLASSKANALABSCHALTUNG_POSITION_SOLL_WERT | unsigned int | - | [%] | - | 0.01 | - | 0 | IndSys_rVSA | Sollposition für Einlaßkanalabschaltung | Target position for intake manifold flap
IWHE1 | 0x16BC | STAT_BEZUGSWINKEL_BEGINN_HAUPTEINSPRITZUNG1_WERT | unsigned int | - | [deg CrS] | - | 0.00293 | - | -90.351389 | InjCrv_phiMI1Des | gewünschter Bezugswinkel für Beginn der MI1 | Desired reference angle for start of MI1
IWVE1 | 0x16BD | STAT_WINKELKOMPONENTE_BEGINN_VOREINSPRITZUNG1_WERT | unsigned int | - | [deg CrS] | - | 0.00293 | - | -90.351389 | InjCrv_phiPiI1Des | gewünschter Winkelkomponente Ansteuerbeginn PiI1 | Desired angle component start of control PiI1
IWVE2 | 0x16BE | STAT_WINKELKOMPONENTE_BEGINN_VOREINSPRITZUNG2_WERT | unsigned int | - | [deg CrS] | - | 0.00293 | - | -90.351389 | InjCrv_phiPiI2Des | gewünschte Winkelkomponente Ansteuerbeginn PiI2 | Desired angle component start of control PiI2
IWVE3 | 0x16BF | STAT_WINKELKOMPONENTE_BEGINN_VOREINSPRITZUNG3_WERT | unsigned int | - | [deg CrS] | - | 0.00293 | - | -90.351389 | InjCrv_phiPiI3Des | gewünschte Winkelkomponente Ansteuerbeginn PiI3 | Desired angle component start of control PiI3
IWNE1 | 0x16C0 | STAT_BEZUGSWINKEL_BEGINN_NACHEINSPRITZUNG1_WERT | unsigned int | - | [deg CrS] | - | 0.00293 | - | -90.351389 | InjCrv_phiPoI1Des | gewünschter Bezugswinkel für Beginn der PoI1 | Desired reference angle for start of PoI1
IWNE2 | 0x16C1 | STAT_BEZUGSWINKEL_BEGINN_NACHEINSPRITZUNG2_WERT | unsigned int | - | [deg CrS] | - | 0.00293 | - | -90.351389 | InjCrv_phiPoI2Des | gewünschter Bezugswinkel für Beginn der PoI2 | Desired reference angle for start of PoI2
IMHE1 | 0x16C2 | STAT_MENGE_HAUPTEINSPRITZUNG1_WERT | unsigned int | - | [mg/inj] | - | 0.001526 | - | 0 | InjCrv_qMI1Des | Sollmenge Haupteinspritzung | Target main injection quantity
IMGV1 | 0x16C3 | STAT_MENGE_VOREINSPRITZUNG1_GRUNDWERT_WERT | unsigned int | - | [mg/inj] | - | 0.001526 | - | 0 | InjCrv_qPiI1Bas_mp | Einspritzmenge PiI1 Grundwert | Injection quantity PiI1 base value
IMVE1 | 0x16C4 | STAT_MENGE_VOREINSPRITZUNG1_WERT | unsigned int | - | [mg/inj] | - | 0.001526 | - | 0 | InjCrv_qPiI1Des | gewünschte Einspritzmenge PiI 1 | Desired injection quantity PiI 1
IMGV2 | 0x16C5 | STAT_MENGE_VOREINSPRITZUNG2_GRUNDWERT_WERT | unsigned int | - | [mg/inj] | - | 0.001526 | - | 0 | InjCrv_qPiI2Bas_mp | Einspritzmenge PiI2 Grundwert | Injection quantity PiI2 base value
IMVE2 | 0x16C6 | STAT_MENGE_VOREINSPRITZUNG2_WERT | unsigned int | - | [mg/inj] | - | 0.001526 | - | 0 | InjCrv_qPiI2Des | gewünschte Einspritzmenge PiI 2 | Desired injection quantity PiI 2
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

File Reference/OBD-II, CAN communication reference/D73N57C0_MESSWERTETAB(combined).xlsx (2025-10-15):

ARG | ID | RESULTNAME | DATENTYP | L/H | EINHEIT | NAME | MUL | DIV | ADD | LABEL | INFO | English
IPABG1 | 0x0432 | STAT_ABGASDRUCK_VOR_PARTIKELFILTER_1_WERT | unsigned int | 0 | hPa | 0 | 0.100000 | 0 | 0.000000 | Exh_pFltPPFltUs | Absolutdruck vor Partikelfilter | Absolute pressure before particle filter
RUPVP | 0x041C | STAT_ABGASDRUCK_VOR_PARTIKELFILTER_SPANNUNG_ROH_WERT | unsigned int | 0 | mV | 0 | 0.076295 | 0 | 0.000000 | Exh_uRawPPFltUs | spannungs rohwert - Abgasdruck vor Partikelfilter | voltage raw value - exhaust gas pressure upstream particle filter
IAAGR | 0x0BB9 | STAT_ABGASRUECKFUEHRSTELLER_ANSTEUERUNG_WERT | unsigned int | 0 | % | 0 | 0.001526 | 0 | 0.000000 | EGRVlv_rPs | AGR-Ventil - Ausgangstastverhältnis | EGR valve - output duty
ITAVO | 0x041E | STAT_ABGASTEMPERATUR_VOR_KATALYSATOR_WERT | unsigned int | 0 | degC | 0 | 0.031281 | 0 | -50.000000 | Exh_tOxiCatUs | Abgastemperatur vor Katalysator - korrigierter Wert | Exhaust gas temperature before catalytic converter - corrected value
ITAVP1 | 0x041B | STAT_ABGASTEMPERATUR_VOR_PARTIKELFILTER_1_WERT | unsigned int | 0 | degC | 0 | 0.031281 | 0 | -50.000000 | Exh_tPFltUs | Abgastemperatur vor Partikelfilter - korrigierter Wert | Exhaust gas temperature before particulate filter - corrected value
RUTVP | 0x041D | STAT_ABGASTEMPERATUR_VOR_PARTIKELFILTER_SPANNUNG_ROH_WERT | unsigned int | 0 | mV | 0 | 0.076295 | 0 | 0.000000 | Exh_uRawTPFltUs | Abgastemperatur vor Partikelfilter - Rohwert | Exhaust gas temperature before particulate filter - raw value
Absch_korr | 0x01B0 | STAT_Absch_korr_WERT | unsigned int | 0 | 0 | 0 | 0.001526 | 0 | 0.000000 | Absch_korr | Korrekturwert Abschaltung | #VALUE!
ACCI_stInActv | 0x0834 | STAT_ACCI_stInActv_WERT | unsigned char | 0 | 0 | 0 | 1.000000 | 0 | 0.000000 | ACCI_stInActv | Status - ACC ist nicht aktiv (für Überwachung) | Status - ACC is not active ( for monitoring)
AccMon_stLim | 0x0835 | STAT_AccMon_stLim_WERT | unsigned char | 0 | 0 | 0 | 1.000000 | 0 | 0.000000 | AccMon_stLim | Status des Reglereingriffs - inaktiv/aktiv | Status of the controller intervention - inactive / active
AccMon_trqDesSel | 0x0836 | STAT_AccMon_trqDesSel_WERT | unsigned long | 0 | Nm | 0 | 0.000015 | 0 | 0.000000 | AccMon_trqDesSel | Zulässiges Sollmoment der Ebene-1 Beschleunigungsüberwachung | Permissible nominal torque of the level -1 acceleration monitoring
AccPed_trqDes | 0x0168 | STAT_AccPed_trqDes_WERT | unsigned long | 0 | Nm | 0 | 0.100000 | 0 | 0.000000 | AccPed_trqDes | Fahrerwunschmoment Sollpfad | Driver torque target path
ActMod_trqClth | 0x07D2 | STAT_ActMod_trqClth_WERT | unsigned int | 0 | Nm | 0 | 0.114443 | 0 | -2500.000000 | ActMod_trqClth | aktuelles Kupplungsmoment | current clutch torque
OBD_PID10_AFS_dmSens | 0x0010 | STAT_AFS_dmSens_WERT | unsigned int | 0 | g/s | 0 | 0.010000 | 0 | 0.000000 | OBD_PID10_AFS_dmSens | Luftmasse von HFM | Air mass of HFM
AFS_dmSensCorr_mp | 0x070B | STAT_AFS_dmSensCorr_mp_WERT | unsigned int | 0 | kg/h | 0 | 0.100000 | 0 | 0.000000 | AFS_dmSensCorr_mp | korrigiertes Luftstromsignal | corrected air flow signal
AFS_facIdlAdjVal_mp | 0x070C | STAT_AFS_facIdlAdjVal_mp_WERT | unsigned int | 0 | 0 | 0 | 0.000122 | 0 | 0.000000 | AFS_facIdlAdjVal_mp | Leerlaufkorrekturfaktor der Driftkompensation | Idle Adjustment factor of drift compensation
AFS_facIdlAdjValUnLim_mp | 0x0712 | STAT_AFS_facIdlAdjValUnLim_mp_WERT | unsigned int | 0 | 0 | 0 | 0.000122 | 0 | 0.000000 | AFS_facIdlAdjValUnLim_mp | Luftmassenkorrekturfaktor im Leerlaufbereich vor Schrittbegrenzung | Air mass correction factor in the idling range before step limit
AFS_facLdAdjVal_mp | 0x070D | STAT_AFS_facLdAdjVal_mp_WERT | unsigned int | 0 | 0 | 0 | 0.000122 | 0 | 0.000000 | AFS_facLdAdjVal_mp | Lastkorrekturfaktor der Driftkompensation | Load correction factor of the drift compensation
AFS_facLdAdjValUnLim_mp | 0x0713 | STAT_AFS_facLdAdjValUnLim_mp_WERT | unsigned int | 0 | 0 | 0 | 0.000122 | 0 | 0.000000 | AFS_facLdAdjValUnLim_mp | Luftmassenkorrekturfaktor im Lastbereich vor Schrittbegrenzung | Air mass correction factor in the load range before step limit
AFS_rNorm_mp | 0x070A | STAT_AFS_rNorm_mp_WERT | unsigned int | 0 | 0 | 0 | 0.000122 | 0 | 0.000000 | AFS_rNorm_mp | Normiertes Luftstromverhältnis | Normalized airflow ratio
AFS_stPsShOff | 0x0711 | STAT_AFS_stPsShOff_WERT | unsigned char | 0 | 0 | 0 | 1.000000 | 0 | 0.000000 | AFS_stPsShOff | HFM-Abschaltbedingungen | HFM shutdown conditions
AFS_stRstLoDrftThres_mp | 0x1880 | STAT_AFS_stRstLoDrftThres_mp_WERT | unsigned char | 0 | 0 | 0 | 1.000000 | 0 | 0.000000 | AFS_stRstLoDrftThres_mp | Status HFM-Erkennung | Status HFM - recognition
AFS_tiRaw | 0x0714 | STAT_AFS_tiRaw_WERT | unsigned long | 0 | us | 0 | 0.050000 | 0 | 0.000000 | AFS_tiRaw | Rohwert der Luftmassenperiode | Raw value of the air mass period
Air_pCACDs | 0x077B | STAT_Air_pCACDs_WERT | unsigned int | 0 | hPa | 0 | 1.000000 | 0 | 0.000000 | Air_pCACDs | PT1-gefilterter Wert des Luftdrucks nach Ladeluftkühler | PT1 - filtered value of the air pressure on the charge air cooler
OBD_PID0B_Air_pSensPIntkVUs | 0x000B | STAT_Air_pSensPIntkVUs_WERT | unsigned char | 0 | kPa | 0 | 1.000000 | 0 | 0.000000 | OBD_PID0B_Air_pSensPIntkVUs | Ladedruck (Sensorwert vor der Korrektur) | Boost pressure ( sensor value before correction )
Air_tEGRClrDs | 0x0777 | STAT_Air_tEGRClrDs_WERT | unsigned int | 0 | degC | 0 | 0.016022 | 0 | -50.000000 | Air_tEGRClrDs | Temperatur nach AGR-Kühler | Temperature after EGR cooler
Air_tEGRClrLPDs | 0x077A | STAT_Air_tEGRClrLPDs_WERT | unsigned int | 0 | degC | 0 | 0.016022 | 0 | -50.000000 | Air_tEGRClrLPDs | Temperatur nach Niederdruck-Abgaskühler | Temperature by low-pressure exhaust-gas cooler
Air_tSensTAFS | 0x0771 | STAT_Air_tSensTAFS_WERT | unsigned int | 0 | degC | 0 | 0.010000 | 0 | -50.000000 | Air_tSensTAFS | Lufttemperatur HFM - aus Sensorkennlinie | Air temperature HFM - from sensor characteristics
OBD_PID0F_Air_tSensTAFS | 0x000F | STAT_Air_tSensTCACDs_WERT | unsigned char | 0 | degC | 0 | 1.000000 | 0 | -40.000000 | OBD_PID0F_Air_tSensTAFS | Ansauglufttemperatur | intake
Air_tSensTEGRClrDs | 0x0776 | STAT_Air_tSensTEGRClrDs_WERT | unsigned int | 0 | degC | 0 | 0.016022 | 0 | -50.000000 | Air_tSensTEGRClrDs | Erfasster Wert der Abgastemperatur nach dem AGR-Kühler | Recorded value of the exhaust gas temperature after the EGR cooler
Air_tSensTEGRClrLPDs | 0x0779 | STAT_Air_tSensTEGRClrLPDs_WERT | unsigned int | 0 | degC | 0 | 0.016022 | 0 | -50.000000 | Air_tSensTEGRClrLPDs | Erfasste Temperatur nach Abgaskühler | Temperature sensed by exhaust gas cooler
Air_uRawTCACDs | 0x0770 | STAT_Air_uRawTCACDs_WERT | unsigned int | 0 | mV | 0 | 0.076295 | 0 | 0.000000 | Air_uRawTCACDs | Spannungs rohwert aus ADC für CACDsT | Voltage raw value from ADC for CACDsT
Air_uRawTEGRClrDs | 0x0775 | STAT_Air_uRawTEGRClrDs_WERT | unsigned int | 0 | mV | 0 | 0.076295 | 0 | 0.000000 | Air_uRawTEGRClrDs | Spannungs rohwert aus dem Temperatursensor nach dem AGR-Kühler | Voltage raw value from the temperature sensor according to the EGR cooler
Air_uRawTEGRClrLPDs | 0x0778 | STAT_Air_uRawTEGRClrLPDs_WERT | unsigned int | 0 | mV | 0 | 0.076295 | 0 | 0.000000 | Air_uRawTEGRClrLPDs | Spannungs rohwert aus dem Temperatursensor nach dem ND-AGR-Kühler | Voltage raw value from the temperature sensor after the LP EGR cooler
AirC_stPsCmpr | 0x07B2 | STAT_AirC_stPsCmpr_WERT | unsigned char | 0 | 0 | 0 | 1.000000 | 0 | 0.000000 | AirC_stPsCmpr | Endgültiger Digitalausgang zur Endstufe des Klimaanlagen-Kompressorstellers | Final digital output to the output stage of the air conditioning compressor plate
AirCtl_arEGRDes | 0x0794 | STAT_AirCtl_arEGRDes_WERT | unsigned int | 0 | cm^2 | 0 | 0.004000 | 0 | 0.000000 | AirCtl_arEGRDes | Sollfläche des Abgasrückführventils | Should surface of the exhaust gas recirculation valve
AirCtl_arEGREst | 0x079B | STAT_AirCtl_arEGREst_WERT | unsigned int | 0 | cm^2 | 0 | 0.004000 | 0 | 0.000000 | AirCtl_arEGREst | geschätzte Istfläche des Abgasrückführventils | Estimated actual surface of the exhaust gas recirculation valve
AirCtl_arTVADes | 0x0795 | STAT_AirCtl_arTVADes_WERT | unsigned int | 0 | cm^2 | 0 | 0.004000 | 0 | 0.000000 | AirCtl_arTVADes | Sollfläche der Drosselklappe | Target area of the throttle valve
AirCtl_arTVAEst | 0x079C | STAT_AirCtl_arTVAEst_WERT | unsigned int | 0 | cm^2 | 0 | 0.004000 | 0 | 0.000000 | AirCtl_arTVAEst | geschätzte Istfläche der Drosselklappe | estimated actual surface of the throttle valve
AirCtl_dmAirDesDyn_r32 | 0x079A | STAT_AirCtl_dmAirDesDyn_r32_WERT | motorola float | 0 | kg/h | 0 | 1.000000 | 0 | 0.000000 | AirCtl_dmAirDesDyn_r32 | dynamisch adaptierter Sollluftmassenstrom in den Motor | dynamically adapted nominal mass air flow into the engine
AirCtl_dmEGRDes_r32 | 0x0796 | STAT_AirCtl_dmEGRDes_r32_WERT | motorola float | 0 | kg/h | 0 | 1.000000 | 0 | 0.000000 | AirCtl_dmEGRDes_r32 | Sollmassenstrom über Abgasrückführventil | Setpoint mass flow through the exhaust gas recirculation valve
AirCtl_dmTVADes_r32 | 0x0797 | STAT_AirCtl_dmTVADes_r32_WERT | motorola float | 0 | kg/h | 0 | 1.000000 | 0 | 0.000000 | AirCtl_dmTVADes_r32 | Sollmassenstrom über Drosselklappe | Target mass flow through the throttle valve
AirCtl_mAirPerCylDesDyn | 0x07AA | STAT_AirCtl_mAirPerCylDesDyn_WERT | unsigned int | 0 | mg/Hub | 0 | 0.100000 | 0 | 0.000000 | AirCtl_mAirPerCylDesDyn | dynamisch adaptierte Luftmasse | dynamically adapted air mass
AirCtl_mDesBasEOM0 | 0x07A8 | STAT_AirCtl_mDesBasEOM0_WERT | unsigned int | 0 | mg/Hub | 0 | 0.100000 | 0 | 0.000000 | AirCtl_mDesBasEOM0 | Luftmasse - Basiswert aus Kennfeld | Air mass - Underlying from mapped
AirCtl_mGovDvt | 0x07A2 | STAT_AirCtl_mGovDvt_WERT | unsigned int | 0 | mg/Hub | 0 | 0.100000 | 0 | 0.000000 | AirCtl_mGovDvt | Luftmasse - Regelabweichung | Air mass - deviation
AirCtl_pTrbnUs_r32 | 0x079D | STAT_AirCtl_pTrbnUs_r32_WERT | motorola float | 0 | hPa | 0 | 1.000000 | 0 | 0.000000 | AirCtl_pTrbnUs_r32 | geschätzter Druck stromaufwärts des Abgasrückführventils | estimated pressure upstream of the exhaust gas recirculation valve
AirCtl_rDesBasEOM0 | 0x07A9 | STAT_AirCtl_rDesBasEOM0_WERT | unsigned int | 0 | 0 | 0 | 0.010000 | 0 | 0.000000 | AirCtl_rDesBasEOM0 | Basiswert der AGR-Stellung | Underlying the EGR position
AirCtl_rDesVal | 0x0793 | STAT_AirCtl_rDesVal_WERT | unsigned int | 0 | 0 | 0 | 0.010000 | 0 | 0.000000 | AirCtl_rDesVal | AGR-Rate - Sollwert | EGR rate - Setpoint
AirCtl_rEGREst | 0x07AD | STAT_AirCtl_rEGREst_r32_WERT | unsigned int | 0 | % | 0 | 0.012207 | 0 | 0.000000 | AirCtl_rEGREst | AGR-Rate - Istwert geschätzt | EGR rate - estimated value
AirCtl_rGovDvtNrm | 0x07A6 | STAT_AirCtl_rGovDvtNrm_WERT | unsigned int | 0 | % | 0 | 0.012207 | 0 | 0.000000 | AirCtl_rGovDvtNrm | Abgasrückführregelung - Regelabweichung | Exhaust gas recirculation control - control deviation
OBD_PID2D_EGRVlv_rGovDvtRel | 0x002D | STAT_AirCtl_rGovDvtNrm_WERT | unsigned char | 0 | % | 0 | 0.781255 | 0 | -100.000000 | OBD_PID2D_EGRVlv_rGovDvtRel | Abgasrückführregler - Regelabweichung | Exhaust gas recirculation control - control deviation
AirCtl_rRatDesDyn_r32 | 0x0799 | STAT_AirCtl_rRatDesDyn_r32_WERT | motorola float | 0 | % | 0 | 1.000000 | 0 | 0.000000 | AirCtl_rRatDesDyn_r32 | dynamisch adaptierte Gesamtsollabgasrückführrate im Motor | dynamically adapted overall target exhaust gas recirculation rate in the engine
AirCtl_rRatDesDyn | 0x07AB | STAT_AirCtl_rRatDesDyn_WERT | unsigned int | 0 | 0 | 0 | 0.010000 | 0 | 0.000000 | AirCtl_rRatDesDyn | dynamisch adaptierte Gesamtsollabgasrückführrate im Motor | dynamically adapted overall target exhaust gas recirculation rate in the engine
AirCtl_rRatGovDvt | 0x07AC | STAT_AirCtl_rRatGovDvt_WERT | unsigned int | 0 | 0 | 0 | 0.010000 | 0 | 0.000000 | AirCtl_rRatGovDvt | Regelabweichung der AGR-Rate | Deviation of the EGR rate
AirCtl_stAirCtlBits | 0x07A0 | STAT_AirCtl_stAirCtlBits_WERT | unsigned long | 0 | 0 | 0 | 1.000000 | 0 | 0.000000 | AirCtl_stAirCtlBits | aktive Abschalt fälle der Luftmassenregelung | active shutdown events of airflow regulation
AirCtl_stDesMax | 0x0798 | STAT_AirCtl_stDesMax_WERT | unsigned char | 0 | 0 | 0 | 1.000000 | 0 | 0.000000 | AirCtl_stDesMax | Status, ob einer der Sollwerte AGR-Rate oder Luftmasse in Max-Begrenzung | Status if any of the setpoints EGR flow or air mass in max limitation
AirCtl_stMon | 0x07A1 | STAT_AirCtl_stMon_WERT | unsigned char | 0 | 0 | 0 | 1.000000 | 0 | 0.000000 | AirCtl_stMon | ursächlicher Abschaltfall der Luftmassenregelung | causal shut-off case the airflow regulation
AirCtl_stMonBits | 0x07A7 | STAT_AirCtl_stMonBits_mp_WERT | unsigned long | 0 | 0 | 0 | 1.000000 | 0 | 0.000000 | AirCtl_stMonBits | selektierte, aktive Abschaltfälle der Luftmassenregelung | selected
AirCtl_stMonBitsRaw_mp | 0x07AE | STAT_AirCtl_stMonBitsRaw_mp_WERT | unsigned long | 0 | 0 | 0 | 1.000000 | 0 | 0.000000 | AirCtl_stMonBitsRaw_mp | Bits vor TimeToClosedLoop-Function | Bits before TimeToClosedLoop -Function
AirCtl_stPrioRat | 0x0792 | STAT_AirCtl_stPrioRat_WERT | unsigned char | 0 | 0 | 0 | 1.000000 | 0 | 0.000000 | AirCtl_stPrioRat | Status, der anzeigt, ob die Gesamtabgasückführrate die priorisierte Sollgrösse ist | Status indicating whether the target magnitude Gesamtabgasückführrate is the prioritized
AirSys_dRED1_mp | 0x1423 | STAT_AirSys_dRED1_mp_WERT | unsigned int | 0 | 0 | 0 | 0.012512 | 0 | -410.000000 | AirSys_dRED1_mp | Ergebnis der LMS-Test Berechnung für dRED1 | Result of the LMS test calculation for dRED1
AirSys_dRED2_mp | 0x1424 | STAT_AirSys_dRED2_mp_WERT | unsigned int | 0 | 0 | 0 | 0.012512 | 0 | -410.000000 | AirSys_dRED2_mp | Ergebnis der LMS-Test Berechnung für dRED2 | Result of the LMS test calculation for dRED2
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

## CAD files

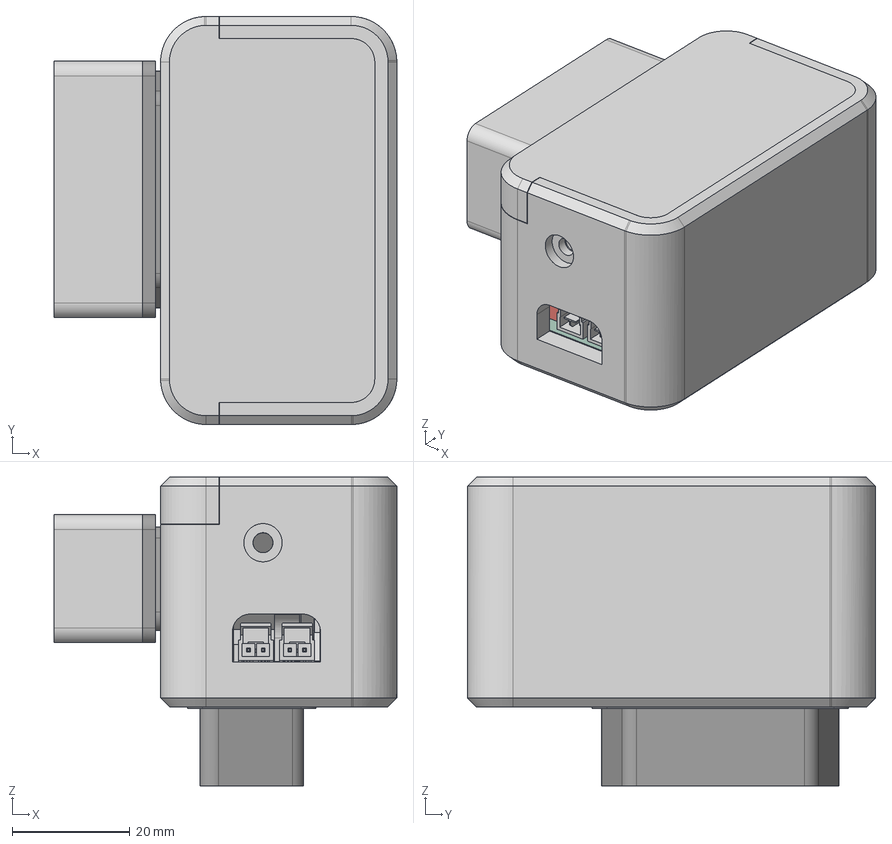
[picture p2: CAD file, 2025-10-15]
CAD/Connector board assembly (lightweight) v10.iges
58.2 x 69.3 x 52.4 mm

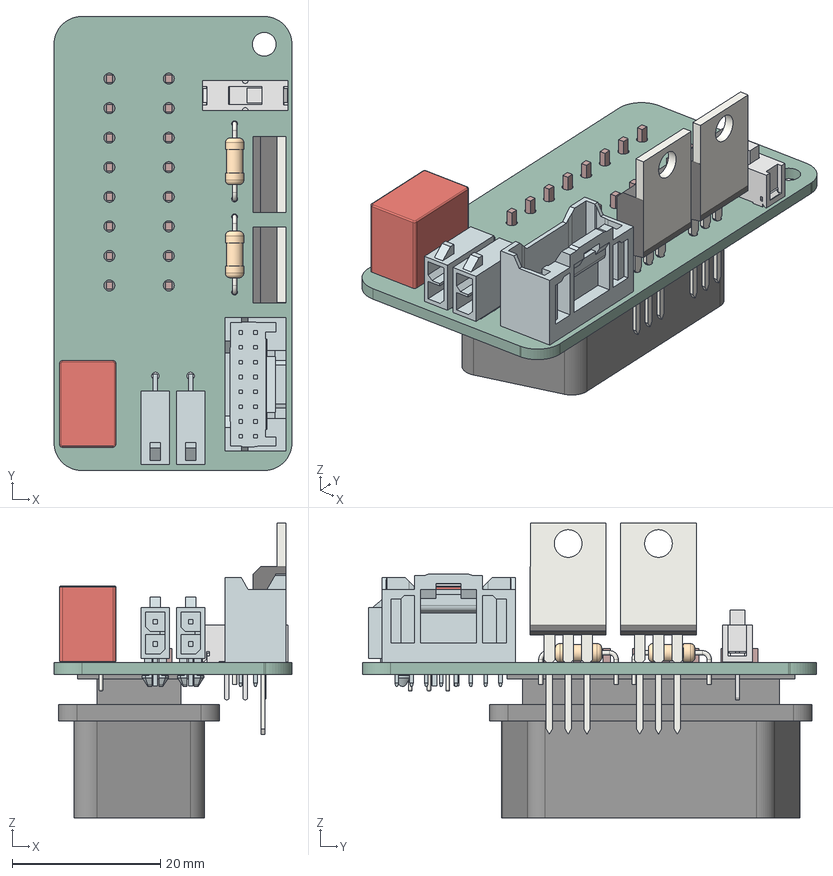
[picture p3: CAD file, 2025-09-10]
PCBs/OBD port power distribution board/V2.7-Connector-board/V2.7-Connector-board.step
32.1 x 61.3 x 39.8 mm
R_Axial_DIN0207_L63mm_D25mm_P1016mm_Horizontal x 2
2125280200wbm000_01 x 2
P:\E-Switch Secure\3D_MODELS_STP_FORMAT\EG1218.stp
5016451620wbm000_01
Converter_DCDC_TRACO_TSR_1_THT
TO-220-3_Vertical x 2
_autosave-V2.7-Connector-board_PCB

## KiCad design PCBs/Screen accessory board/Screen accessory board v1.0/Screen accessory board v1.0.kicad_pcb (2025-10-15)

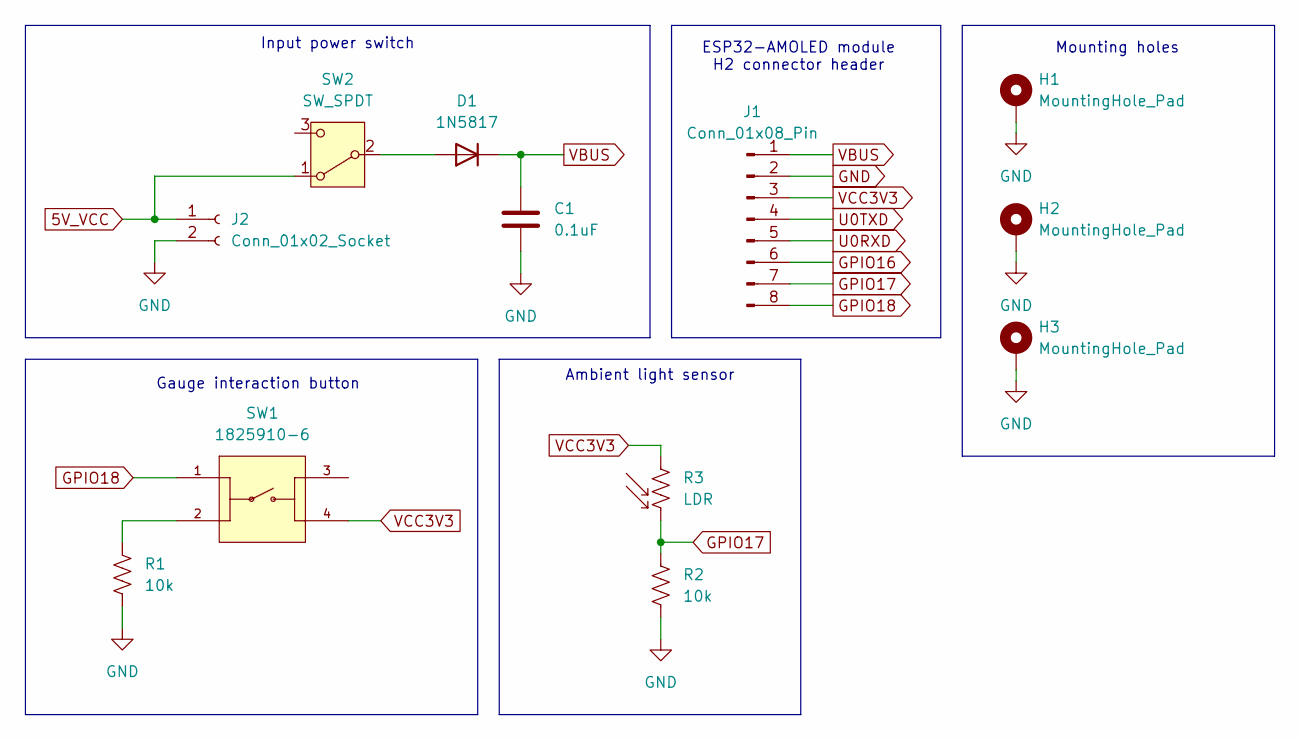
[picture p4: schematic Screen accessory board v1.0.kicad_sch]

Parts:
C1: 0.1uF; C_Disc_D4.3mm_W1.9mm_P5.00mm
D1: 1N5817; D_DO-15_P12.70mm_Horizontal
H1, H2, H3: MountingHole_Pad; MountingHole_2.2mm_M2_Pad
J1: Conn_01x08_Pin; PinHeader_1x08_P2.54mm_Vertical
J2: Conn_01x02_Socket; Molex_Nano-Fit_105313-xx02_1x02_P2.50mm_Horizontal
R1, R2: 10k; R_Axial_DIN0207_L6.3mm_D2.5mm_P10.16mm_Horizontal
R3: LDR; R_LDR_5.1x4.3mm_P3.4mm_Vertical_(respaced_silkscreen)
SW1: 1825910-6; SW_1825910-6-4; PARTREV C10
SW2: SW_SPDT; SW_1218_EWI

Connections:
5V_VCC: J2.1, SW2.1 (A)
GND: C1.2, H1.1, H2.1, H3.1, J1.2, J2.2, R1.1, R2.1
GPIO16: J1.6
GPIO17: J1.7, R2.2, R3.2
GPIO18: J1.8, SW1.1
unnamed: D1.2 (A), SW2.2 (B)
unnamed: R1.2, SW1.2
U0RXD: J1.5
U0TXD: J1.4
VBUS: C1.1, D1.1 (K), J1.1
VCC3V3: J1.3, R3.1, SW1.4

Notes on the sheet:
Gauge interaction button
Input power switch
ESP32-AMOLED module H2 connector header
Ambient light sensor
Mounting holes

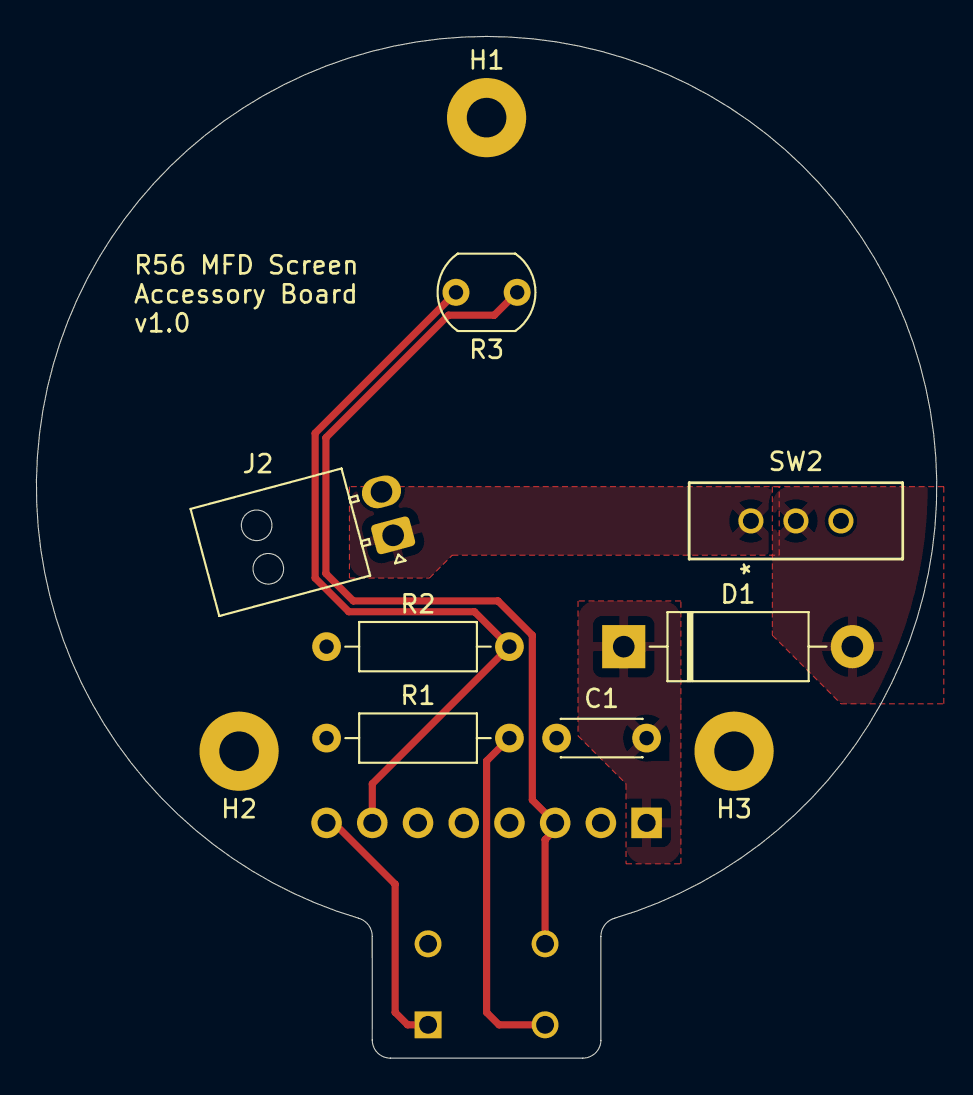
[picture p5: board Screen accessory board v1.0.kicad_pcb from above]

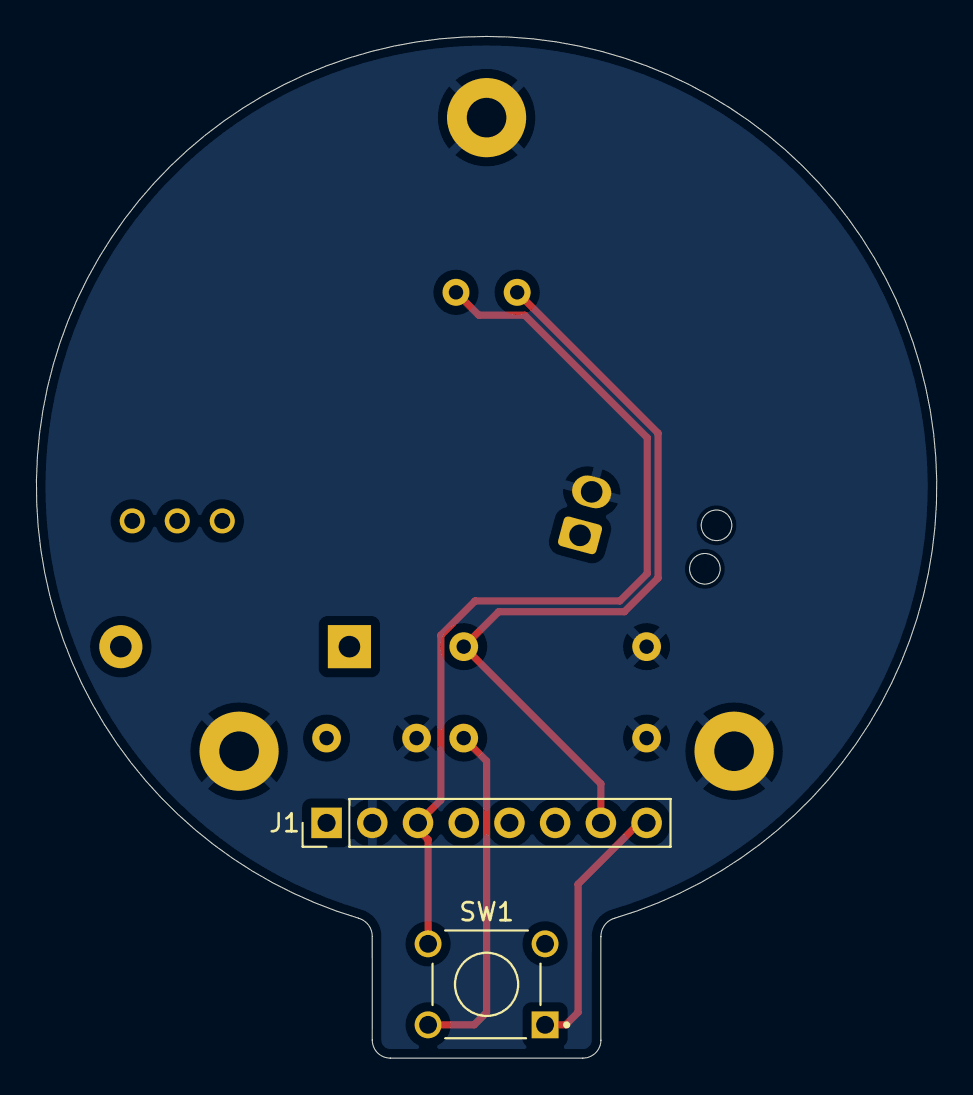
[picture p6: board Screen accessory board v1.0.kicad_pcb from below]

Board: 2 copper layers, 50.0 x 56.8 mm, 12 parts (2 on the bottom side), 8 nets.

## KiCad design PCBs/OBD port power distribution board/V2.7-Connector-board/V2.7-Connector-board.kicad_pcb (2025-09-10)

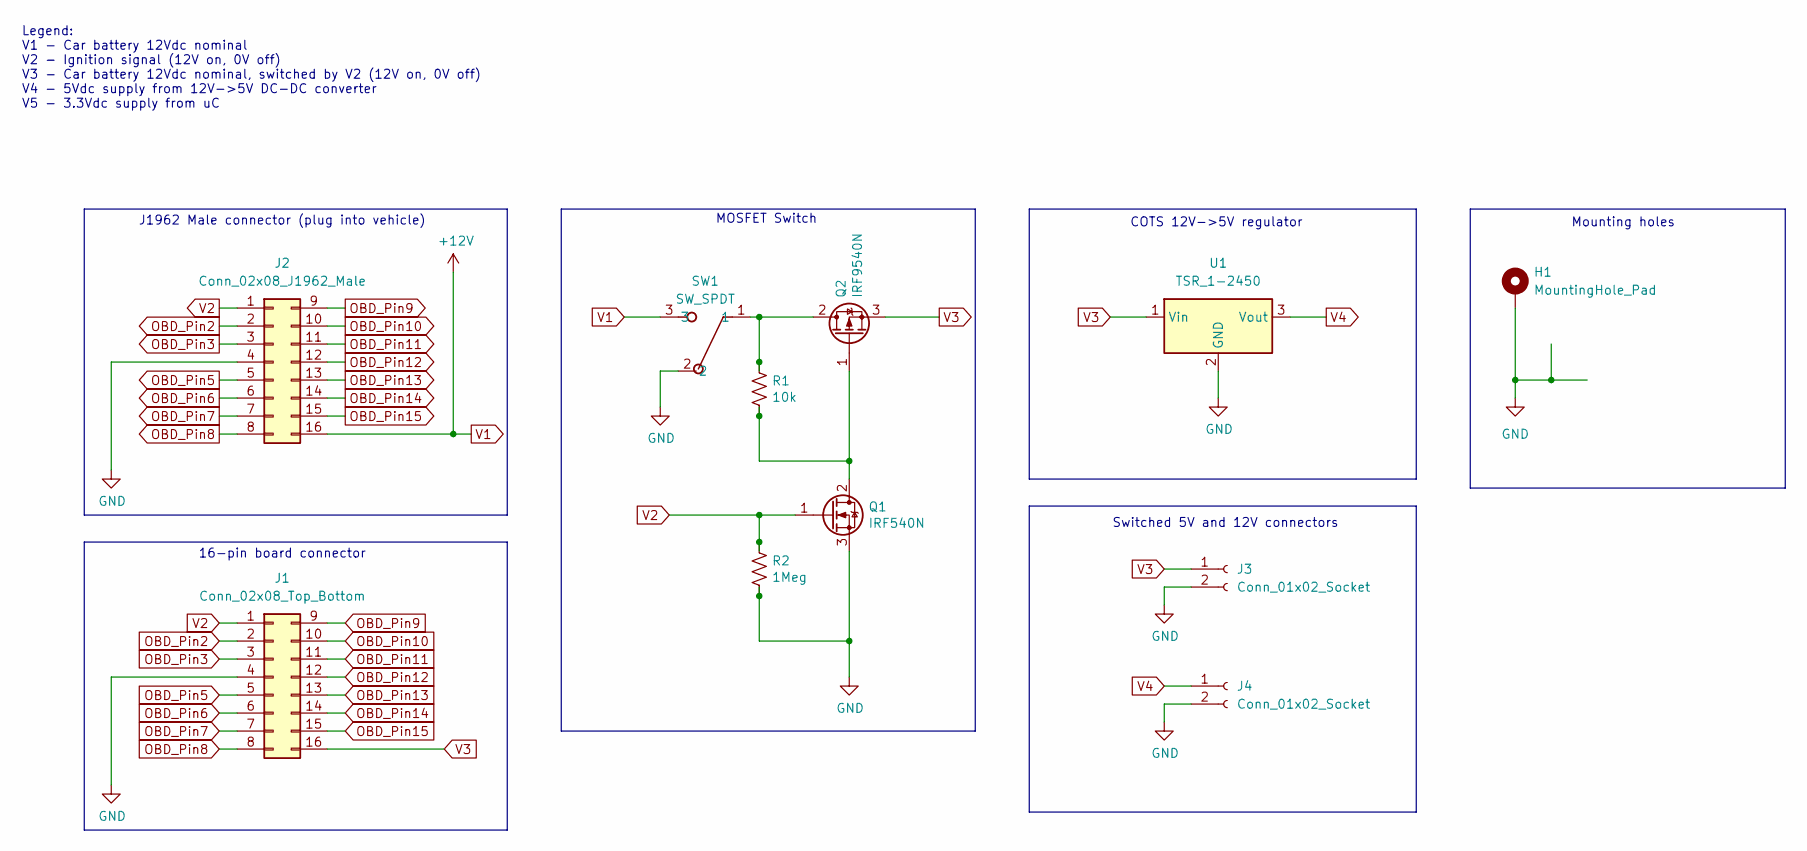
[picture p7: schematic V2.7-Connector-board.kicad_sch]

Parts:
H1: MountingHole_Pad; MountingHole_3.2mm_M3_Pad
J1: Conn_02x08_Top_Bottom; CONN16_5016451620_MOL_Renumbered
J2: Conn_02x08_J1962_Male; OBD-II_Male_Connector_Renumbered
J3, J4: Conn_01x02_Socket; CONN02_2125280200_MOL
Q1: IRF540N; TO-220-3_Vertical
Q2: IRF9540N; TO-220-3_Vertical
R1: 10k; R_Axial_DIN0207_L6.3mm_D2.5mm_P10.16mm_Horizontal
R2: 1Meg; R_Axial_DIN0207_L6.3mm_D2.5mm_P10.16mm_Horizontal
SW1: SW_SPDT; SW_1218_EWI
U1: TSR_1-2450; Converter_DCDC_TRACO_TSR-1_THT

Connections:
GND: H1.1, J1.4, J2.4, J3.2, J4.2, Q1.3 (S), R2.1, SW1.2, U1.2 (GND)
unnamed: Q1.2 (D), Q2.1 (G), R1.1
unnamed: Q2.2 (D), R1.2, SW1.1
OBD_Pin2: J1.2, J2.2
OBD_Pin3: J1.3, J2.3
OBD_Pin5: J1.5, J2.5
OBD_Pin6: J1.6, J2.6
OBD_Pin7: J1.7, J2.7
OBD_Pin8: J1.8, J2.8
OBD_Pin9: J1.9, J2.9
OBD_Pin10: J1.10, J2.10
OBD_Pin11: J1.11, J2.11
OBD_Pin12: J1.12, J2.12
OBD_Pin13: J1.13, J2.13
OBD_Pin14: J1.14, J2.14
OBD_Pin15: J1.15, J2.15
V1: J2.16, SW1.3
V2: J1.1, J2.1, Q1.1 (G), R2.2
V3: J1.16, J3.1, Q2.3 (S), U1.1 (Vin)
V4: J4.1, U1.3 (Vout)

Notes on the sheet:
COTS 12V->5V regulator
MOSFET Switch
Switched 5V and 12V connectors
J1962 Male connector (plug into vehicle)
Legend: V1 - Car battery 12Vdc nominal V2 - Ignition signal (12V on, 0V off) V3 - Car battery 12Vdc nominal, switched by V2 (12V on, 0V off) V4 - 5Vdc supply from 12V->5V DC-DC converter V5 - 3.3Vdc supply from uC
Mounting holes
16-pin board connector

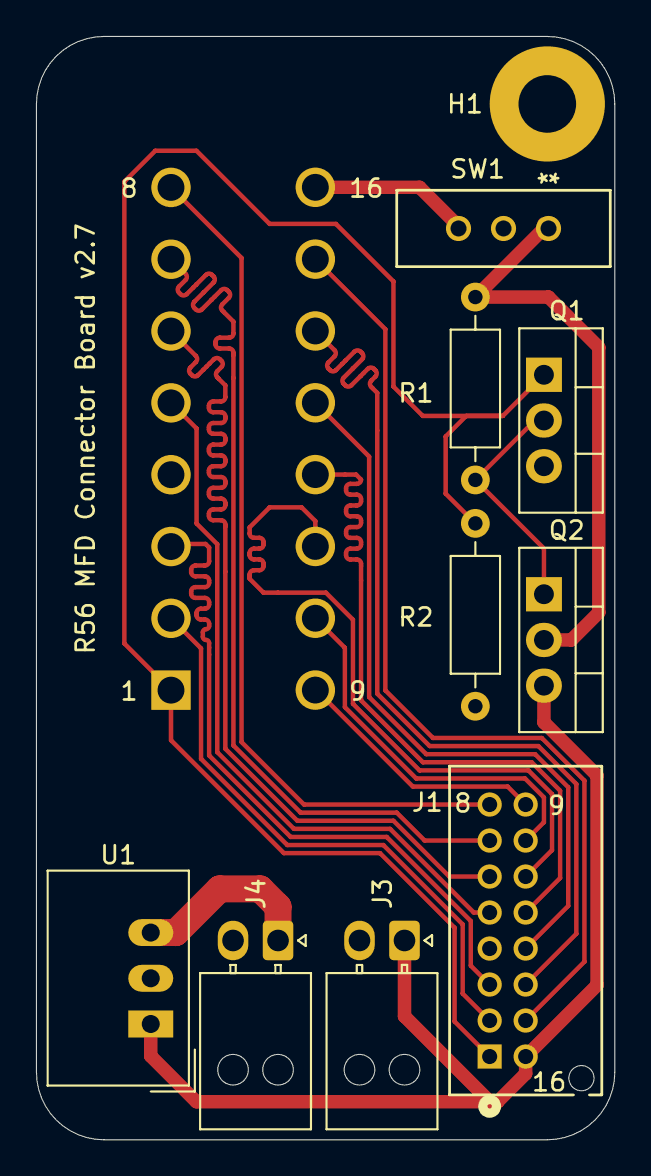
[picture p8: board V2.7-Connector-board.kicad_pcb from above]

Board: 2 copper layers, 32.1 x 61.3 mm, 11 parts (1 on the bottom side), 20 nets.

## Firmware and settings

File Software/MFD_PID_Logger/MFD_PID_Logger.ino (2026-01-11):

// SET_LOOP_TASK_STACK_SIZE(1024 * 16); 

// #include "Gauge.h"

#include <WiFi.h>
#include "ELMduino.h"

/******************************************************************************
*                                   DEFINES                                   *
******************************************************************************/
#define BTN_PIN 18
#define BRIGHTNESS_SENSOR_PIN 17

#define BTN_1_ACTION 1   // how many ms to press button to switch gauges
#define BTN_2_ACTION 500 // how many ms to press button for secondary action (action is TBD)

#define BRIGHTNESS_LO 155 // screen brightness setting
#define BRIGHTNESS_HI 255
#define BRIGHTNESS_LO_BOUND 1000 // ambient light sensor value
#define BRIGHTNESS_HYST 200 // hysteresis value for light sensor
#define BRIGHTNESS_INTVL (1 * 1000) // when to check ambient light level (ms)

#define WIFI_SSID "WiFi_OBDII"
#define WIFI_PW ""

#define RX_PASS 0
#define RX_FAIL 1
#define RX_NONE 2

#define HPA_TO_PSI 0.0145038
#define MPA_TO_PSI 145.037738
#define L_TO_GAL 0.264172

/******************************************************************************
*                                  TYPEDEFS                                   *
******************************************************************************/
// enum to go through while collecting OBD data
typedef enum
{
  PID_OIL_TEMP,
  PID_COOLANT_TEMP,
  // PID_RANGE,
  PID_AMBIENT_PRESS,
  PID_BOOST_PRESS,
  PID_OIL_PRESS,
  PID_FUEL_PRESS,
  PID_BRAKE_PRESS,
  PID_BRAKE_PRESS2,
  PID_ENGINE_SPEED,
  PID_GEAR,
  PID_BATTERY_VOLTAGE,
  PID_AFR_TARGET,
  PID_AFR_ACTUAL,
  PID_SPEED,
  PID_TRIP_TIME,
  PID_FUEL_CONS,
  PID_MAP,
  PID_IAT,
  PID_MAF,
  PID_MAX_STATE,
} PID_States;

/******************************************************************************
*                            MODULE-LEVEL VARIABLES                           *
******************************************************************************/
// static Gauge mainGauge;
static ELM327 main_ELM327;
static bool buttonPressed = false;
// static GaugeData data; 
static IPAddress server(192, 168, 0, 10);
static WiFiClient client;

/******************************************************************************
*                              HELPER FUNCTIONS                               *
******************************************************************************/
// ISR for button
void IRAM_ATTR RegButton() {
  if (digitalRead(BTN_PIN)) {
    buttonPressed = true;
  }
  else {
    buttonPressed = false;
  }
}

int CheckScannerState(ELM327 scanner)
{
  if (scanner.nb_rx_state == ELM_SUCCESS)
  {
    return RX_PASS;
  }
  else if (scanner.nb_rx_state != ELM_GETTING_MSG)
  {
    return RX_FAIL;
  }
  return RX_NONE;
}

/******************************************************************************
*                                    MACROS                                   *
******************************************************************************/
#define INCREMENT_PID_STATE(PID) do { \
  PID = PID_States((int)PID + 1); \
  } while(0)

#define MSG_RECEIVED(scanner) (scanner.nb_rx_state == ELM_SUCCESS)
#define MSG_NOT_RECEIVED(scanner) (scanner.nb_rx_state != ELM_GETTING_MSG)

/******************************************************************************
*                                INIT FUNCTION                                *
******************************************************************************/

void setup() {
  // SET_LOOP_TASK_STACK_SIZE(1024 * 64); 

  // IPAddress server(192, 168, 0, 10);
  // WiFiClient client;

  Serial.begin(115200);
  Serial.println("Starting...");

  // initialize gauge library
  // mainGauge.begin();
  // mainGauge.update(data);

  // configure ISR for button
  pinMode(BTN_PIN, INPUT);
  attachInterrupt(digitalPinToInterrupt(BTN_PIN), RegButton, CHANGE);

  // setup wifi for ELM327
  WiFi.mode(WIFI_AP);
  WiFi.begin(WIFI_SSID);
  // WiFi.begin(WIFI_SSID, WIFI_PW);

  while (WiFi.status() != WL_CONNECTED)
  {
    delay(500);
    Serial.print(".");
  }

  Serial.println("");
  Serial.println("Connected to Wifi");
  Serial.println("IP address: ");
  Serial.println(WiFi.localIP());

  if (client.connect(server, 35000))
    Serial.println("connected");
  else
  {
    Serial.println("connection failed");
    while(1);
  }
  // false for debug msg OFF, true for debug msg ON
  main_ELM327.begin(client, false, 2000);  
  
  Serial.printf("timetag,sensor,service,PID,raw_value,proc_value,unit,\n");

  // mainGauge.begin();
}


/******************************************************************************
*                                 MAIN DRIVER                                 *
******************************************************************************/
void loop() {
  static PID_States currPID = PID_OIL_TEMP;
  static float latestAmbientPressure_PSI = 14.7; 
  static double trip_dist_mi = 0;
  static double start_fuel_gal = 0;

  switch (currPID){
    
    case PID_OIL_TEMP:
    {
      uint8_t service = 0x22; uint16_t PID = 0x5822;
      const char* sensor = "OilTemp"; const char* unit = "degC";
      int rawVal = main_ELM327.processPID(service, PID, 1, 1, 1, 1);
      float processedVal = rawVal - 60;
      if (main_ELM327.nb_rx_state == ELM_SUCCESS)
      {
        Serial.printf("%li,%s,0x%x,0x%x,%d,%.2f,%s\n", millis(), sensor, service, PID, rawVal, processedVal, unit);
        INCREMENT_PID_STATE(currPID);
      }
      else if (main_ELM327.nb_rx_state != ELM_GETTING_MSG)
      {
        // main_ELM327.printError();
        Serial.printf("%li,%s,0x%x,0x%x,N/A,N/A,N/A\n", millis(), sensor, service, PID);
        INCREMENT_PID_STATE(currPID);
      }

      break;
    }
    case PID_COOLANT_TEMP:
    {
      uint8_t service = 0x22; uint16_t PID = 0x4300;
      const char* sensor = "CoolantTemp"; const char* unit = "degC";
      int rawVal = main_ELM327.processPID(service, PID, 1, 1, 1, 1);
      float processedVal = 0.75 * rawVal - 48;
      if (main_ELM327.nb_rx_state == ELM_SUCCESS)
      {
        Serial.printf("%li,%s,0x%x,0x%x,%d,%.2f,%s\n", millis(), sensor, service, PID, rawVal, processedVal, unit);
        INCREMENT_PID_STATE(currPID);
      }
      else if (main_ELM327.nb_rx_state != ELM_GETTING_MSG)
      {
        // main_ELM327.printError();
        Serial.printf("%li,%s,0x%x,0x%x,N/A,N/A,N/A\n", millis(), sensor, service, PID);
        INCREMENT_PID_STATE(currPID);
      }
      // int scannerState = CheckScannerState(main_ELM327);
      // if (scannerState == RX_PASS){
      //   Serial.printf("%li,%s,0x%x,0x%x,%d,%.2f,%s\n", millis(), sensor, service, PID, rawVal, processedVal, unit);
      //   INCREMENT_PID_STATE(currPID);
      // }
      // else {
      //   Serial.printf("%li,%s,0x%x,0x%x,N/A,N/A,N/A\n", millis(), sensor, service, PID);
      //   INCREMENT_PID_STATE(currPID);
      // }
      break;
    }
    case PID_AMBIENT_PRESS:
    {
      uint8_t service = 0x22; uint16_t PID = 0x5834;
      const char* sensor = "AmbientPressure"; const char* unit = "hPa";
      float processedVal = main_ELM327.processPID(service, PID, 1, 1, (0.0390625 * HPA_TO_PSI), 0);
      
      if (main_ELM327.nb_rx_state == ELM_SUCCESS)
      {
        latestAmbientPressure_PSI = processedVal;
        Serial.printf("%li,%s,0x%x,0x%x,%d,%.2f,%s\n", millis(), sensor, service, PID, 9999, processedVal, unit);
        INCREMENT_PID_STATE(currPID);
      }
      else if (main_ELM327.nb_rx_state != ELM_GETTING_MSG)
      {
        // main_ELM327.printError();
        Serial.printf("%li,%s,0x%x,0x%x,N/A,N/A,N/A\n", millis(), sensor, service, PID);
        INCREMENT_PID_STATE(currPID);
      }
      break;
    }
    case PID_BOOST_PRESS:
    {
      uint8_t service = 0x22; uint16_t PID = 0x4205;
      const char* sensor = "BoostPressure"; const char* unit = "hPa";
      float processedVal  = main_ELM327.processPID(service, PID, 1, 1, (0.078125 * HPA_TO_PSI), 0) - latestAmbientPressure_PSI;
      
      if (main_ELM327.nb_rx_state == ELM_SUCCESS)
      {
        Serial.printf("%li,%s,0x%x,0x%x,%d,%.2f,%s\n", millis(), sensor, service, PID, 9999, processedVal, unit);
        INCREMENT_PID_STATE(currPID);
      }
      else if (main_ELM327.nb_rx_state != ELM_GETTING_MSG)
      {
        // main_ELM327.printError();
        Serial.printf("%li,%s,0x%x,0x%x,N/A,N/A,N/A\n", millis(), sensor, service, PID);
        INCREMENT_PID_STATE(currPID);
      }
      break;
    }
    case PID_OIL_PRESS:
    {
      uint8_t service = 0x22; uint16_t PID = 0x586F;
      const char* sensor = "OilPressure"; const char* unit = "hPa";
      float processedVal = main_ELM327.processPID(service, PID, 1, 1, HPA_TO_PSI, 0) - latestAmbientPressure_PSI;
      
      if (main_ELM327.nb_rx_state == ELM_SUCCESS)
      {
        Serial.printf("%li,%s,0x%x,0x%x,%d,%.2f,%s\n", millis(), sensor, service, PID, 9999, processedVal, unit);
        INCREMENT_PID_STATE(currPID);
      }
      else if (main_ELM327.nb_rx_state != ELM_GETTING_MSG)
      {
        // main_ELM327.printError();
        Serial.printf("%li,%s,0x%x,0x%x,N/A,N/A,N/A\n", millis(), sensor, service, PID);
        INCREMENT_PID_STATE(currPID);
      }
      // int scannerState = CheckScannerState(main_ELM327);
      // if (scannerState == RX_PASS){
        
      //   Serial.printf("%li,%s,0x%x,0x%x,%d,%.2f,%s\n", millis(), sensor, service, PID, rawVal, processedVal, unit);
      //   INCREMENT_PID_STATE(currPID);
      // }
      // else {
      //   Serial.printf("%li,%s,0x%x,0x%x,N/A,N/A,N/A\n", millis(), sensor, service, PID);
      //   INCREMENT_PID_STATE(currPID);
      // }
      break;
    }
    case PID_FUEL_PRESS:
    {
      uint8_t service = 0x22; uint16_t PID = 0x58EF;
      const char* sensor = "FuelRailPress(Filtered)"; const char* unit = "MPa";
      float processedVal = main_ELM327.processPID(service, PID, 1, 1, (0.0005 * MPA_TO_PSI), 0) - latestAmbientPressure_PSI;
      
      if (main_ELM327.nb_rx_state == ELM_SUCCESS)
      {
        Serial.printf("%li,%s,0x%x,0x%x,%d,%.2f,%s\n", millis(), sensor, service, PID, 9999, processedVal, unit);
        INCREMENT_PID_STATE(currPID);
      }
      else if (main_ELM327.nb_rx_state != ELM_GETTING_MSG)
      {
        // main_ELM327.printError();
        Serial.printf("%li,%s,0x%x,0x%x,N/A,N/A,N/A\n", millis(), sensor, service, PID);
        INCREMENT_PID_STATE(currPID);
      }
      // int scannerState = CheckScannerState(main_ELM327);
      // if (scannerState == RX_PASS){
        
      //   Serial.printf("%li,%s,0x%x,0x%x,%d,%.2f,%s\n", millis(), sensor, service, PID, rawVal, processedVal, unit);
      //   INCREMENT_PID_STATE(currPID);
      // }
      // else {
      //   Serial.printf("%li,%s,0x%x,0x%x,N/A,N/A,N/A\n", millis(), sensor, service, PID);
      //   INCREMENT_PID_STATE(currPID);
      // }
      break;
    }
    case PID_BRAKE_PRESS:
    {
      uint8_t service = 0x22; uint16_t PID = 0x58B7;
      const char* sensor = "BrakePressure"; const char* unit = "hPa";
      int rawVal = main_ELM327.processPID(service, PID, 1, 1, 1, 1);
      float processedVal = rawVal;
      if (main_ELM327.nb_rx_state == ELM_SUCCESS)
      {
        Serial.printf("%li,%s,0x%x,0x%x,%d,%.2f,%s\n", millis(), sensor, service, PID, rawVal, processedVal, unit);
        INCREMENT_PID_STATE(currPID);
      }
      else if (main_ELM327.nb_rx_state != ELM_GETTING_MSG)
      {
        // main_ELM327.printError();
        Serial.printf("%li,%s,0x%x,0x%x,N/A,N/A,N/A\n", millis(), sensor, service, PID);
        INCREMENT_PID_STATE(currPID);
      }
      // int scannerState = CheckScannerState(main_ELM327);
      // if (scannerState == RX_PASS){
        
      //   Serial.printf("%li,%s,0x%x,0x%x,%d,%.2f,%s\n", millis(), sensor, service, PID, rawVal, processedVal, unit);
      //   INCREMENT_PID_STATE(currPID);
      // }
      // else {
      //   Serial.printf("%li,%s,0x%x,0x%x,N/A,N/A,N/A\n", millis(), sensor, service, PID);
      //   INCREMENT_PID_STATE(currPID);
      // }
      break;
    }
    case PID_BRAKE_PRESS2:
    {
      uint8_t service = 0x22; uint16_t PID = 0x58B7;
      const char* sensor = "AmbientPressMinusBrakeBoosterPress"; const char* unit = "hPa";
      int rawVal = main_ELM327.processPID(service, PID, 1, 1, 1, 1);
      float processedVal = 0.0390625 * rawVal;
      if (main_ELM327.nb_rx_state == ELM_SUCCESS)
      {
        Serial.printf("%li,%s,0x%x,0x%x,%d,%.2f,%s\n", millis(), sensor, service, PID, rawVal, processedVal, unit);
        INCREMENT_PID_STATE(currPID);
      }
      else if (main_ELM327.nb_rx_state != ELM_GETTING_MSG)
      {
        // main_ELM327.printError();
        Serial.printf("%li,%s,0x%x,0x%x,N/A,N/A,N/A\n", millis(), sensor, service, PID);
        INCREMENT_PID_STATE(currPID);
      }
      // int scannerState = CheckScannerState(main_ELM327);
      // if (scannerState == RX_PASS){
        
      //   Serial.printf("%li,%s,0x%x,0x%x,%d,%.2f,%s\n", millis(), sensor, service, PID, rawVal, processedVal, unit);
      //   INCREMENT_PID_STATE(currPID);
      // }
      // else {
      //   Serial.printf("%li,%s,0x%x,0x%x,N/A,N/A,N/A\n", millis(), sensor, service, PID);
      //   INCREMENT_PID_STATE(currPID);
      // }
      break;
    }
    // case PID_RANGE:
    // {
    //   uint8_t service = 0x22; uint16_t PID = 0x4411;
    //   const char* sensor = "Range"; const char* unit = "km?";
    //   int rawVal = main_ELM327.processPID(service, PID, 1, 1, 1, 1);
    //   float processedVal = 10 * rawVal;
    //   if (main_ELM327.nb_rx_state == ELM_SUCCESS)
    //   {
    //     Serial.printf("%li,%s,0x%x,0x%x,%d,%.2f,%s\n", millis(), sensor, service, PID, rawVal, processedVal, unit);
    //     INCREMENT_PID_STATE(currPID);
    //   }
    //   else if (main_ELM327.nb_rx_state != ELM_GETTING_MSG)
    //   {
    //     // main_ELM327.printError();
    //     Serial.printf("%li,%s,0x%x,0x%x,N/A,N/A,N/A\n", millis(), sensor, service, PID);
    //     INCREMENT_PID_STATE(currPID);
    //   }
    //   // int scannerState = CheckScannerState(main_ELM327);
    //   // if (scannerState == RX_PASS){
        
    //   //   Serial.printf("%li,%s,0x%x,0x%x,%d,%.2f,%s\n", millis(), sensor, service, PID, rawVal, processedVal, unit);
    //   //   INCREMENT_PID_STATE(currPID);
    //   // }
    //   // else {
    //   //   Serial.printf("%li,%s,0x%x,0x%x,N/A,N/A,N/A\n", millis(), sensor, service, PID);
    //   //   INCREMENT_PID_STATE(currPID);
    //   // }
    //   break;
    // }
    
    case PID_ENGINE_SPEED:
    {
      uint8_t service = 0x22; uint16_t PID = 0x4807;
      const char* sensor = "EngineSpeed"; const char* unit = "rpm";
      int rawVal = main_ELM327.processPID(service, PID, 1, 1, 1, 0);
      float processedVal = 0.25 * rawVal;
      if (main_ELM327.nb_rx_state == ELM_SUCCESS)
      {
        Serial.printf("%li,%s,0x%x,0x%x,%d,%.2f,%s\n", millis(), sensor, service, PID, rawVal, processedVal, unit);
        INCREMENT_PID_STATE(currPID);
      }
      else if (main_ELM327.nb_rx_state != ELM_GETTING_MSG)
      {
        // main_ELM327.printError();
        Serial.printf("%li,%s,0x%x,0x%x,N/A,N/A,N/A\n", millis(), sensor, service, PID);
        INCREMENT_PID_STATE(currPID);
      }
      // int scannerState = CheckScannerState(main_ELM327);
      // if (scannerState == RX_PASS){
        
      //   Serial.printf("%li,%s,0x%x,0x%x,%d,%.2f,%s\n", millis(), sensor, service, PID, rawVal, processedVal, unit);
      //   INCREMENT_PID_STATE(currPID);
      // }
      // else {
      //   Serial.printf("%li,%s,0x%x,0x%x,N/A,N/A,N/A\n", millis(), sensor, service, PID);
      //   INCREMENT_PID_STATE(currPID);
      // }
      break;
    }
    case PID_GEAR:
    {
      uint8_t service = 0x22; uint16_t PID = 0x5881;
      const char* sensor = "Gear"; const char* unit = "-";
      int rawVal = main_ELM327.processPID(service, PID, 1, 1, 1, 1);
      float processedVal = rawVal;
      if (main_ELM327.nb_rx_state == ELM_SUCCESS)
      {
        Serial.printf("%li,%s,0x%x,0x%x,%d,%.2f,%s\n", millis(), sensor, service, PID, rawVal, processedVal, unit);
        INCREMENT_PID_STATE(currPID);
      }
      else if (main_ELM327.nb_rx_state != ELM_GETTING_MSG)
      {
        // main_ELM327.printError();
        Serial.printf("%li,%s,0x%x,0x%x,N/A,N/A,N/A\n", millis(), sensor, service, PID);
        INCREMENT_PID_STATE(currPID);
      }
      // int scannerState = CheckScannerState(main_ELM327);
      // if (scannerState == RX_PASS){
        
      //   Serial.printf("%li,%s,0x%x,0x%x,%d,%.2f,%s\n", millis(), sensor, service, PID, rawVal, processedVal, unit);
      //   INCREMENT_PID_STATE(currPID);
      // }
      // else {
      //   Serial.printf("%li,%s,0x%x,0x%x,N/A,N/A,N/A\n", millis(), sensor, service, PID);
      //   INCREMENT_PID_STATE(currPID);
      // }
      break;
    }
    case PID_BATTERY_VOLTAGE:
    {
      uint8_t service = 0x22; uint16_t PID = 0x460C;
      const char* sensor = "BatteryVoltage"; const char* unit = "V";
      int rawVal = main_ELM327.processPID(service, PID, 1, 1, 1, 1);
      float processedVal = 0.023481 * rawVal;
      if (main_ELM327.nb_rx_state == ELM_SUCCESS)
      {
        Serial.printf("%li,%s,0x%x,0x%x,%d,%.2f,%s\n", millis(), sensor, service, PID, rawVal, processedVal, unit);
        INCREMENT_PID_STATE(currPID);
      }
      else if (main_ELM327.nb_rx_state != ELM_GETTING_MSG)
      {
        // main_ELM327.printError();
        Serial.printf("%li,%s,0x%x,0x%x,N/A,N/A,N/A\n", millis(), sensor, service, PID);
        INCREMENT_PID_STATE(currPID);
      }
      // int scannerState = CheckScannerState(main_ELM327);
      // if (scannerState == RX_PASS){
        
      //   Serial.printf("%li,%s,0x%x,0x%x,%d,%.2f,%s\n", millis(), sensor, service, PID, rawVal, processedVal, unit);
      //   INCREMENT_PID_STATE(currPID);
      // }
      // else {
      //   Serial.printf("%li,%s,0x%x,0x%x,N/A,N/A,N/A\n", millis(), sensor, service, PID);
      //   INCREMENT_PID_STATE(currPID);
      // }
      break;
    }
    
    case PID_AFR_TARGET:
    {
      uint8_t service = 0x22; uint16_t PID = 0x5816;
      const char* sensor = "LambdaSetpoint"; const char* unit = "-";
      int rawVal = main_ELM327.processPID(service, PID, 1, 1, 1, 1);
      float processedVal = rawVal * 0.000244141;
      if (main_ELM327.nb_rx_state == ELM_SUCCESS)
      {
        Serial.printf("%li,%s,0x%x,0x%x,%d,%.2f,%s\n", millis(), sensor, service, PID, rawVal, processedVal, unit);
        INCREMENT_PID_STATE(currPID);
      }
      else if (main_ELM327.nb_rx_state != ELM_GETTING_MSG)
      {
        // main_ELM327.printError();
        Serial.printf("%li,%s,0x%x,0x%x,N/A,N/A,N/A\n", millis(), sensor, service, PID);
        INCREMENT_PID_STATE(currPID);
      }
      // int scannerState = CheckScannerState(main_ELM327);
      // if (scannerState == RX_PASS){
        
      //   Serial.printf("%li,%s,0x%x,0x%x,%d,%.2f,%s\n", millis(), sensor, service, PID, rawVal, processedVal, unit);
      //   INCREMENT_PID_STATE(currPID);
      // }
      // else {
      //   Serial.printf("%li,%s,0x%x,0x%x,N/A,N/A,N/A\n", millis(), sensor, service, PID);
      //   INCREMENT_PID_STATE(currPID);
      // }
      break;
    }
    case PID_AFR_ACTUAL:
    {
      uint8_t service = 0x22; uint16_t PID = 0x5889;
      const char* sensor = "LambdaActual"; const char* unit = "-";
      int rawVal = main_ELM327.processPID(service, PID, 1, 1, 1, 1);
      float processedVal = 0.000244141 * rawVal;
      if (main_ELM327.nb_rx_state == ELM_SUCCESS)
      {
        Serial.printf("%li,%s,0x%x,0x%x,%d,%.2f,%s\n", millis(), sensor, service, PID, rawVal, processedVal, unit);
        INCREMENT_PID_STATE(currPID);
      }
      else if (main_ELM327.nb_rx_state != ELM_GETTING_MSG)
      {
        // main_ELM327.printError();
        Serial.printf("%li,%s,0x%x,0x%x,N/A,N/A,N/A\n", millis(), sensor, service, PID);
        INCREMENT_PID_STATE(currPID);
      }
      // int scannerState = CheckScannerState(main_ELM327);
      // if (scannerState == RX_PASS){
        
      //   Serial.printf("%li,%s,0x%x,0x%x,%d,%.2f,%s\n", millis(), sensor, service, PID, rawVal, processedVal, unit);
      //   INCREMENT_PID_STATE(currPID);
      // }
      // else {
      //   Serial.printf("%li,%s,0x%x,0x%x,N/A,N/A,N/A\n", millis(), sensor, service, PID);
      //   INCREMENT_PID_STATE(currPID);
      // }
      break;
    }
    case PID_SPEED:
    {
      // uint8_t service = 0x22; uint16_t PID = 0x4AB1;
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

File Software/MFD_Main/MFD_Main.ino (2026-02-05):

// SET_LOOP_TASK_STACK_SIZE(1024 * 16); 

#include "Gauge.h"

#include <WiFi.h>
#include "ELMduino.h"

/******************************************************************************
*                                   DEFINES                                   *
******************************************************************************/
#define BTN_PIN 18
#define BRIGHTNESS_SENSOR_PIN 17

#define BTN_1_ACTION 1   // how many ms to press button to switch gauges
#define BTN_2_ACTION 500 // how many ms to press button for secondary action (action is TBD)

#define BRIGHTNESS_LO 155 // screen brightness setting
#define BRIGHTNESS_HI 255
#define BRIGHTNESS_LO_BOUND 1000 // ambient light sensor value
#define BRIGHTNESS_HYST 200 // hysteresis value for light sensor
#define BRIGHTNESS_INTVL (1 * 1000) // when to check ambient light level (ms)

#define WIFI_SSID "WiFi_OBDII"
#define WIFI_PW ""

#define HPA_TO_PSI 0.0145038
#define MPA_TO_PSI 145.037738
#define L_TO_GAL 0.264172


/******************************************************************************
*                            FUNCTION PROTOTYPES                              *
******************************************************************************/
void HandleOilTemp(double valueFromELM);
void HandleCoolantTemp(double valueFromELM);
void HandleBaroPress(double valueFromELM);
void HandleBoostPress(double valueFromELM);
void HandleOilPress(double valueFromELM);
void HandleFuelPress(double valueFromELM);
void HandleGaugeUpdate(double valueFromELM);
void HandleNULL(double valueFromELM);
// void IRAM_ATTR RegButton();
void ProcessPidState();
uint8_t CalculateBrightness();

/******************************************************************************
*                                  TYPEDEFS                                   *
******************************************************************************/
// enum to go through while collecting OBD data
typedef enum
{
  PID_OIL_TEMP,
  PID_COOLANT_TEMP,
  PID_BARO_PRESS,
  PID_BOOST_PRESS,
  PID_OIL_PRESS,
  PID_FUEL_PRESS,
  PID_INTAKE_PRESS,
  PID_TRIP_TIME,
  PID_VEHICLE_SPEED,
  PID_FUEL_CONS,
  PID_AIR_FUEL_RATIO,
  PID_MASS_AIRFLOW,
  PID_MAX_STATE,
} PID_States;

// General definition for PID handler function
// Note: Match general function prototype for handler
using PIDHandlerFunc = void (*)(double value); 

// Indexable definition of PID request
struct PIDRequestToFunction
{
    uint8_t PIDIndex;          // index of PID array
    PIDHandlerFunc onSuccess;  // name of function which post processes the data from processPID()
};

// Array map of each PID request : handler function pair
constexpr PIDRequestToFunction PIDToFunctionMap[] =
{
  //  PID_state enumeration:function name
  { PID_OIL_TEMP,       HandleOilTemp     },
  { PID_COOLANT_TEMP,   HandleCoolantTemp },
  { PID_BARO_PRESS,     HandleBaroPress   },
  { PID_BOOST_PRESS,    HandleBoostPress  },
  { PID_OIL_PRESS,      HandleOilPress    },
  { PID_FUEL_PRESS,     HandleFuelPress   },
  { PID_INTAKE_PRESS,   HandleNULL        },
  { PID_TRIP_TIME,      HandleNULL        },
  { PID_VEHICLE_SPEED,  HandleNULL        },
  { PID_FUEL_CONS,      HandleNULL        },
  { PID_AIR_FUEL_RATIO, HandleNULL        },
  { PID_MASS_AIRFLOW,   HandleNULL        },
  { PID_MAX_STATE,      HandleGaugeUpdate      },
};


/******************************************************************************
*                            MODULE-LEVEL VARIABLES                           *
******************************************************************************/
static Gauge mainGauge;
static ELM327 main_ELM327;
static bool buttonPressed = false;
static GaugeData data; 
static IPAddress server(192, 168, 0, 10);
static WiFiClient client;

// Array with parameters to processPID()
// source for service 0x01 PIDs: https://en.wikipedia.org/wiki/OBD-II_PIDs#Standard_PIDs
// source for service 0x22 PIDs: https://thesecretingredient.neocities.org/bmw/dme/n55/
static int ProcessPIDsArray [(int)PID_MAX_STATE + 1][4] = {
  // {Service ID, Parameter ID, num responses, num bytes of response}
  {0x22, 0x5822, 1, 1}, // Oil temperature
  {0x01, 0x0005, 1, 1}, // Coolant temperature
  {0x22, 0x5834, 1, 2}, // Baro/ambient pressure
  {0x22, 0x4205, 1, 2}, // Boost pressure*
  {0x22, 0x586F, 1, 2}, // Oil pressure*
  {0x22, 0x58EF, 1, 2}, // Fuel rail pressure*
  {0x22, 0x580B, 1, 2}, // MAP
  {0x22, 0x5800, 1, 2}, // Trip time
  {0x01, 0x000D, 1, 1}, // Vehicle speed mi/hr**
  {0x22, 0x4403, 1, 4}, // Fuel consumption since last oil change***
  {0x22, 0x5889, 1, 2}, // Lambda
  {0x22, 0x5818, 1, 1}, // MAF
  {0x01, 0x0000, 1, 1}, // Placeholder
  // *   Subtract this from the baro pressure to get true pressure value
  // **  Integrate this to get trip distance
  // *** Subtract this from first reading to get trip consumption
};

// Scale and offset for each parameter
static float ProcessPIDsScalingArray [(int)PID_MAX_STATE + 1][2] = {
  // {scale, offset}
  {1, -60},                      // Oil temperature
  {1, -40},                      // Coolant temperature
  {(0.0390625 * HPA_TO_PSI), 0}, // Baro/ambient pressure
  {(0.078125 * HPA_TO_PSI), 0},  // Boost pressure
  {HPA_TO_PSI, 0},               // Oil pressure*
  {(0.0005 * MPA_TO_PSI), 0},    // Fuel rail pressure
  {(0.0390625 * HPA_TO_PSI), 0}, // MAP
  {0.100000001, 0},              // Trip time
  {0.621371, 0},                 // Vehicle speed mi/hr
  {(0.00012207 * L_TO_GAL), 0},  // Fuel consumption since last oil change**
  {0.000244141, 0},              // Lambda
  {4, 0},                        // MAF
  {999, 999},                    // Placeholder
};

/******************************************************************************
*                                    MACROS                                   *
******************************************************************************/
// Increment state variable for which PID to read
#define INCREMENT_PID_STATE(stateVar) do { \
  stateVar = PID_States( ((int)stateVar + 1) % ((int)PID_MAX_STATE + 1) ) ; \
  } while(0)

// Increment gauge between oiltemp, coolant temp, etc.
#define INCREMENT_GAUGE_TYPE(type) do { \
  type = (GaugeType)( ((int)type + 1) % GAUGE_TYPE_MAX ); \
  } while(0)

// Wrapper for ELMDuino ProcessPID()
#define REQUEST_DATA(scanner, index) (\
  scanner.processPID( \
    ProcessPIDsArray[index][0], \
    ProcessPIDsArray[index][1],  \
    ProcessPIDsArray[index][2],  \
    ProcessPIDsArray[index][3],  \
    ProcessPIDsScalingArray[index][0],  \
    ProcessPIDsScalingArray[index][1] \
  ) \
)

/******************************************************************************
*                         ACTION HANDLER FUNCTIONS                            *
******************************************************************************/

void HandleOilTemp(double valueFromELM)
{ 
  data.OilTemp_C = (int)valueFromELM; 
  // Serial.printf("%li: OilTemp=%d degC\n", millis(), data.OilTemp_C);
}
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

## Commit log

2024-08-16 updated gauge painter library to print numbers only as needed (does not print a number that hasn't changed since the last print to reduce flickering effect)
2024-08-20 updated gauge painter with more efficient index painting (only prints indices different from last gauge state)
2025-06-01 begin writing main program which polls OBD-II parameters live
    [PID conversions.xlsx]
2025-06-05 updated main program to use button and screen
2025-06-16 added new test file which writes a CSV of processed PID data to serial port for validation of PID conversions (use CoolTerm to log)
    [6-15-2025_DriveAround.xlsx, CoolTerm Capture 2025-06-15 12-32-42.csv]
2025-08-10 Begin testing with WaveShare ESP32 AMOLED module. Have test program with 1 index being toggled on and off
2025-08-11 added custom font and number printing
2025-09-09 added index printing fn which only draws as needed
2025-09-10 added sensor icon display (WIP w/ hardcoded vars)
2025-09-10 Added connector board PCB
    [V2.7-Connector-board-B_Cu.gbr, V2.7-Connector-board-B_Mask.gbr, V2.7-Connector-board-B_Paste.gbr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]
2025-09-13 UI is functional for inputs of coolant temp, oil temp, oil pressure, fuel pressure, boost pressure
2025-09-20 Created LVGL filesystem driver to incorporate fonts onto SD card
2025-09-28 transfered display driver functions from Gauge.cpp to separate display driver files; added SD card file structure for reference
2025-09-28 changed MFD_Main to use new AMOLED gauge library. Having an issue where program crashes on processPID()
    [Gauge.cpp, Gauge.h, MFD_Main.ino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]
2025-09-30 working program for full MFD; Have correct temperature displays
    [MFD_Main.ino]
2025-10-05 add ambient light sensor support for brightness setting (ADC via GPIO pin 17)
2025-10-15 Re-organize MFD repository
    [D73N57C0_MESSWERTETAB(combined).xlsx, LVGL_Index_locations.xlsx, PID conversions.xlsx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]
2025-10-15 added CAD for connector board housing, pictures
    [Connector board assembly (lightweight) v10.iges]
2025-10-15 Add MOSFET switch sim
2025-12-27 Added new test/logging program for OBD-II extended service (0x22) addressing
    [Tool32 definitions.xlsx]
2025-12-29 Rewrite of state machine logic to make adding future PIDs more modular, corrections to processing of pressure PIDs using service 22
    [12-27-2025_DriveAround.xlsx]
2026-01-11 Add new logs, logging program changes, CAD for screen assembly
    [01-06-2026_DriveAround.xlsx]
2026-01-12 Add partial BOM, update READMEs
    [BOM.xlsx]
2026-02-05 WIP trip computer screen, added capability to switch between two GUIs
